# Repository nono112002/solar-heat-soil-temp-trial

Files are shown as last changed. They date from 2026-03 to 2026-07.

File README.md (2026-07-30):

# 太陽熱養生 温度測定プロジェクト

太陽熱を利用した土壌養生（消毒）の効果を「感覚」ではなく「データ」で検証する。
畑の複数地点・複数深度に温度センサーを設置し、リアルタイムで計測・記録・可視化するIoTシステム。

---

## システム概要図

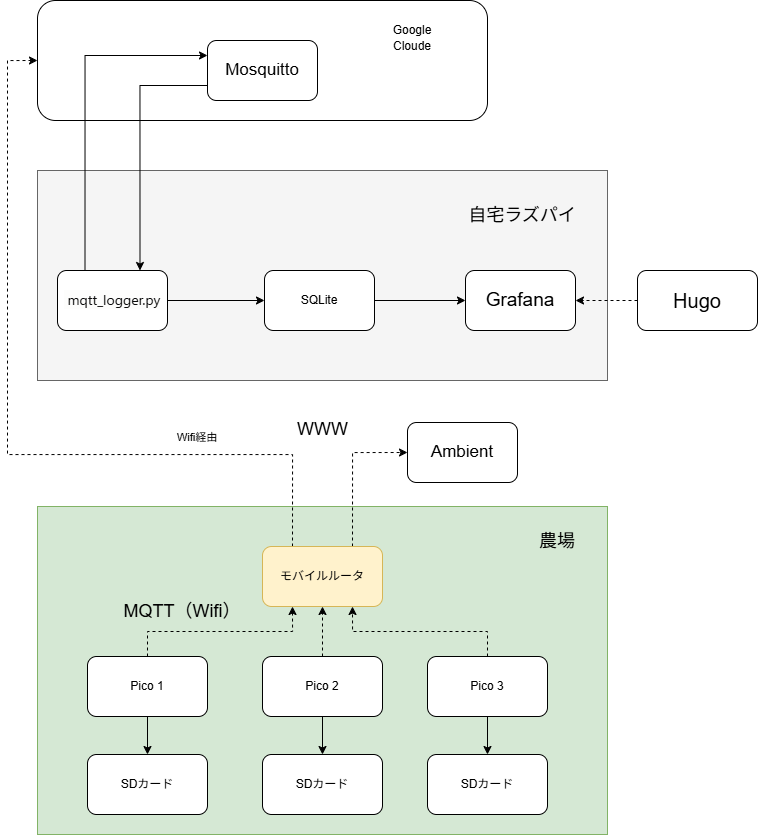
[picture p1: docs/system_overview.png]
システム概要図


### データの流れ

1. **農場の PicoBox（3台）** が30分ごとに温度を計測
2. **カシムラ モバイルルータ**（SORACOM SIM）経由で WiFi → LTE でインターネットに出る
3. **Google Cloud（GCE）上の Mosquitto** が MQTT メッセージを受信
4. **GCE の mqtt_logger** が SQLite に保存 + **Flask API** で配信
5. **自宅の Raspberry Pi** も GCE の MQTT を購読し、ローカル SQLite に保存
6. **Grafana**（ラズパイ）と **ポートフォリオHP**（GitHub Pages）でグラフ表示

> データは GCE（API配信用）と自宅ラズパイ（Grafana用）の2箇所に保存される。

---

## ブラウザからの確認方法

自宅 LAN 内のPCから以下にアクセス：

| 画面 | URL | 内容 |
|---|---|---|
| Grafana ダッシュボード | http://192.168.0.10:3000 | Zone-A/B/C の温度グラフ（メインの確認画面） |
| ポートフォリオ HP | http://192.168.0.10:1313 | プロジェクト紹介ページ |
| ライブデータ（3分割） | http://192.168.0.10:1313/dashboard.html | Grafana の3パネルを iFrame で一覧表示 |

> Grafana は匿名アクセス有効（ログイン不要）。ポートフォリオ HP（Hugo）は手動起動が必要（後述）。

---

## ハードウェア構成

### PicoBox（3台共通）

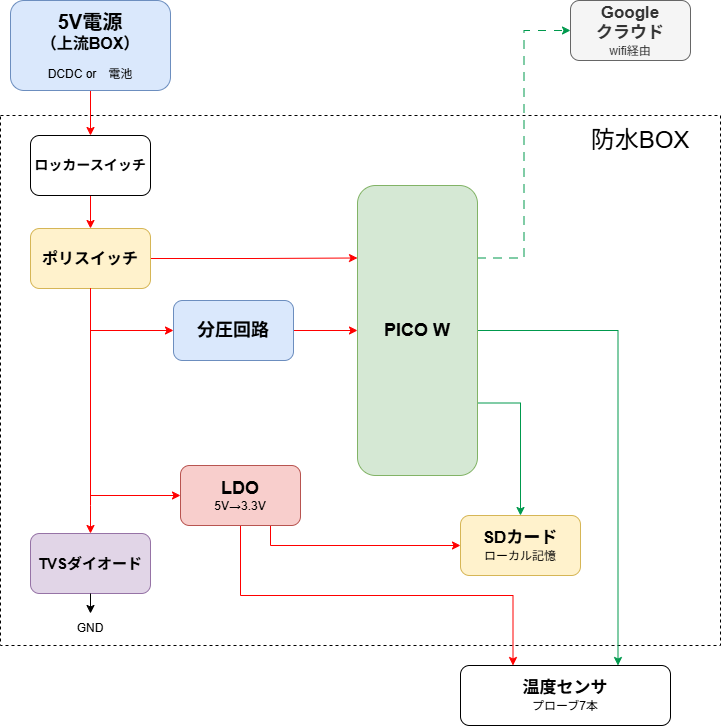
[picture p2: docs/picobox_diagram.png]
PicoBox 回路構成


| 部材 | 仕様 | 数量 |
|---|---|---|
| Raspberry Pi Pico W | RP2040 + CYW43439 | 3 |
| 温度センサー | DS18B20（防水型） | 21（7本 × 3台） |
| PCB（PicoBox） | JLCPCB 発注・自作基板 | 3 |
| SDカード | ローカルバックアップ用 | 3 |
| 防水BOX | 屋外設置用 | 3 |

### GPIO 割り当て（3台共通）

| 機能 | GPIO |
|---|---|
| DS18B20 × 7（S1〜S7） | GP8〜GP14 |
| SDカード（SPI） | GP2〜GP5、CD=GP6 |
| TX LED | GP15 |
| 主電源監視（ADC） | GP26 |

### センサー配置（1台あたり7本）

| ラベル | 位置 | 深さ |
|---|---|---|
| S1_center_10cm | 中央 | 10cm |
| S2_center_25cm | 中央 | 25cm |
| S3_center_40cm | 中央 | 40cm |
| S4_edge_10cm | エッジ | 10cm |
| S5_edge_25cm | エッジ | 25cm |
| S6_edge_40cm | エッジ | 40cm |
| S7_outdoor | 外気温 | — |

### ゾーン区分

| ゾーン | 区 | 処理内容 |
|---|---|---|
| zone-a | 区A | 標準区（たい肥＋菌＋ビニール） |
| zone-b | 区B | 対照・菌なし（たい肥＋ビニール） |
| zone-c | 区C | 対照・ビニールなし（たい肥のみ） |

### PicoBox ↔ ゾーン対応

| PicoBox筐体 | config.py ZONE | 設置エリア |
|---|---|---|
| ユニット3 | `zone-a` | 区A（標準区） |
| ユニット2 | `zone-b` | 区B（対照・菌なし） |
| ユニット1 | `zone-c` | 区C（対照・ビニールなし） |

> 筐体番号と区が一致しないが、config.py の ZONE で正しいゾーン名を送信するため
> DB上は常に物理エリアと一致する。

### 通信機器

| 機器 | 型番 | 役割 |
|---|---|---|
| モバイルルータ | カシムラ KD-249 | PicoBox の WiFi アクセスポイント → LTE 接続 |
| SIM | SORACOM Air plan-K2（KDDI） | モバイルデータ通信（月500MB、実使用量 約1.1MB/月） |

---

## サーバー構成（Raspberry Pi 4）

| コンポーネント | バージョン | 役割 | 自動起動 |
|---|---|---|---|
| mqtt_logger.py | Python 3.13 / paho-mqtt 2.1.0 | GCE の MQTT を購読 → SQLite に保存 | systemd ✅ |
| SQLite | 3.46.1 | データ保存（/var/lib/solar-heat/data.db） | — |
| Grafana | 13.0.1 + frser-sqlite-datasource | データ可視化（:3000） | systemd ✅ |
| Mosquitto | 2.0.21 | ローカル MQTT ブローカー（現在未使用） | systemd ✅ |
| Hugo | 0.131.0 + Blowfish v2.88.1 | ポートフォリオ HP（:1313） | **手動起動** |

### ラズパイの情報

| 項目 | 値 |
|---|---|
| OS | Debian 13 (trixie) aarch64 |
| ホスト名 | hp-server |
| IPアドレス | 192.168.0.10 |
| ストレージ | 28GB（24% 使用） |
| RAM | 3.7GB |

---

## クラウド構成（Google Cloud）

MQTT の中継サーバーとして GCE を使用。農場（モバイル回線）と自宅（固定回線）を繋ぐ。

| 項目 | 値 |
|---|---|
| プロジェクト | solar-heat-mqtt |
| VM名 | mqtt-broker |
| マシンタイプ | e2-micro（無料枠） |
| リージョン | us-central1-a |
| 外部IP | 34.58.138.105 |
| OS | Debian 12 (bookworm) |
| サービス | Mosquitto 2.0.11（:1883、認証あり）、mqtt_logger、Flask API（gunicorn :5000） |
| DB | /var/lib/solar-heat/data.db |
| API | https://34-58-138-105.sslip.io/api/（nginx + certbot SSL） |

---

## ソフトウェア構成

### ファイル一覧

```
solar-heat/
├── README.md                          # 本ファイル
├── pico/
│   ├── main.py                        # Pico W ファームウェア（MicroPython）
│   ├── config.py                      # WiFi/MQTT/ゾーン設定（.gitignore）
│   └── test_power_led.py              # LED テスト用
├── server/
│   ├── README.md                      # Pi セットアップ手順
│   ├── mqtt_logger.py                 # MQTT → SQLite 保存
│   ├── mqtt_logger.service            # systemd ユニットファイル
│   ├── mosquitto/
│   │   └── mosquitto.conf             # MQTT ブローカー設定
│   └── grafana/
│       └── provisioning/
│           ├── datasources/sqlite.yml
│           ├── dashboards/dashboards.yml
│           └── dashboards/solar-heat.json
├── docs/
│   ├── system_overview.png            # システム概要図
│   ├── picobox_diagram.png            # PicoBox 回路構成図
│   ├── server_design.md               # サーバー設計書（詳細）
│   ├── sensor_registry.md             # センサー台帳
│   ├── pcb_spec.md                    # PCB 設計仕様
│   ├── parts.md                       # 部品表
│   └── blog/                          # ブログ記事素材
└── kicad/                             # PCB 設計データ（KiCad）

GCE 上の配置（リポジトリ外、VM 内に直接配置）:
/home/nono/solar-heat/server/mqtt_logger.py  # MQTT ロガー（サービス実行元）
/var/lib/solar-heat/data.db                  # SQLite DB（API配信元）
/etc/systemd/system/mqtt_logger.service
```

### Pico ファームウェアの動作

`pico/main.py` は以下のサイクルを30分ごとに繰り返す：

1. DS18B20 × 7本から温度を読み取り
2. SDカードに CSV で記録（ローカルバックアップ）
3. WiFi ON → カシムラに接続
4. MQTT で GCE に温度データを送信（`solar-heat/{zone}/{label}`）
5. MQTT でデバイスステータスを送信（`solar-heat/{zone}/status`）
6. 電源電圧が 4.0V 未満なら電源アラートを送信
7. WiFi OFF → スリープ（ウォッチドッグタイマー feed しながら）

**ウォッチドッグタイマー**: 8秒タイムアウト。熱暴走等でフリーズした場合に自動リセットする。
起動直後に有効化され、メインループ内の各ステップおよびスリープ中（1秒ごと）に feed する。

### LED 表示パターン

| 状態 | 意味 |
|---|---|
| 消灯 | 正常 |
| 常時点灯 | 電源異常（bus_v < 4.0V） |
| 低速点滅 | SD異常 |
| 高速点滅 | 電源異常 + SD異常 |

### MQTT トピック

| トピック | ペイロード例 |
|---|---|
| `solar-heat/zone-a/S1_center_10cm` | `{"time": "2026-07-12T16:00:00", "temp": 29.88}` |
| `solar-heat/zone-a/status` | `{"zone": "zone-a", "bus_v": 5.02, "sd_status": "ok", "uptime_min": 120}` |
| `solar-heat/zone-a/power_alert` | `{"zone": "zone-a", "bus_v": 3.8, "alert": "main_power_lost"}` |

### SQLite テーブル

| テーブル | カラム | 内容 |
|---|---|---|
| temperature | timestamp, zone, label, temp | 温度データ |
| device_status | zone, bus_v, sd_status, wifi_attempts, uptime_min | デバイス状態 |
| power_alert | zone, bus_v, alert | 電源異常アラート |

---

## セットアップ手順

### 1. Raspberry Pi

詳細は `server/README.md` を参照。

```bash
# リポジトリ取得
cd ~ && git clone https://github.com/nono112002/solar-heat-soil-temp-trial.git solar-heat

# Mosquitto（ローカル、現在未使用だが残してある）
sudo ln -s ~/solar-heat/server/mosquitto/mosquitto.conf /etc/mosquitto/conf.d/solar-heat.conf
sudo systemctl restart mosquitto

# SQLite 保存先
sudo mkdir -p /var/lib/solar-heat && sudo chown nono:nono /var/lib/solar-heat

# mqtt_logger サービス
sudo ln -s ~/solar-heat/server/mqtt_logger.service /etc/systemd/system/mqtt_logger.service
sudo systemctl daemon-reload && sudo systemctl enable --now mqtt_logger

# Grafana（別途 apt で導入済み）
# プラグイン: grafana cli plugins install frser-sqlite-datasource
```

### 2. PicoBox（各台）

```bash
# ファームウェア書き込み（USB 接続状態で）
mpremote connect COMx fs cp pico/main.py :main.py
mpremote connect COMx fs cp pico/config.py :config.py
```

`config.py` は `.gitignore` で管理外。各台で ZONE と SENSOR_PINS を設定する。
リポジトリに `config_pico1.py` / `config_pico2.py` / `config_pico3.py` を用意してある。

```python
# config_example.py を参照。実際の値は config_pico*.py に記入（gitignore対象）
WIFI_SSID     = "your_ssid"
WIFI_PASSWORD = "your_password"
MQTT_BROKER   = "your_mqtt_host"
MQTT_PORT     = 1883
MQTT_USER     = "your_user"
MQTT_PASS     = "your_pass"
ZONE          = "zone-a"  # zone-a / zone-b / zone-c
```

### 3. Hugo（ポートフォリオ HP）

```bash
# ラズパイで実行
cd ~ && git clone https://github.com/nono112002/nono112002.github.io.git portfolio
cd portfolio && git submodule update --init --recursive

# 起動（手動）
hugo server --bind 0.0.0.0 --baseURL http://192.168.0.10 -p 1313
```

### 4. Google Cloud（MQTT 中継 + バックアップ）

```bash
# gcloud CLI でセットアップ済み
# プロジェクト: solar-heat-mqtt
# VM: mqtt-broker (e2-micro, us-central1-a)
# Mosquitto 認証: server/.env を参照
# ファイアウォール: tcp:1883 を開放

# バックアップロガー
# /opt/solar-heat/mqtt_logger.py — ローカル Mosquitto を購読し SQLite に保存
# /var/lib/solar-heat/data.db — ラズパイと同一スキーマのバックアップDB
# systemd: mqtt_logger.service（自動起動）
```

---

## 運用コマンド集

### ラズパイ（SSH: `ssh nono@192.168.0.10`）

```bash
# ログ確認
journalctl -u mqtt_logger -f

# MQTT 受信状況をリアルタイム確認
mosquitto_sub -h $MQTT_HOST -u $MQTT_USER -P $MQTT_PASS -t 'solar-heat/#' -v

# DB 確認
sqlite3 /var/lib/solar-heat/data.db 'SELECT * FROM temperature ORDER BY id DESC LIMIT 10;'
sqlite3 /var/lib/solar-heat/data.db 'SELECT zone, COUNT(*) FROM temperature GROUP BY zone;'

# ソフト更新
cd ~/solar-heat && git pull && sudo systemctl restart mqtt_logger

# Hugo 起動
cd ~/portfolio && git pull --recurse-submodules
hugo server --bind 0.0.0.0 --baseURL http://192.168.0.10 -p 1313
```

### GCE（`gcloud compute ssh mqtt-broker --zone=us-central1-a`）

```bash
# Mosquitto ログ確認
sudo journalctl -u mosquitto -f

# 接続テスト
mosquitto_pub -h localhost -u $MQTT_USER -P $MQTT_PASS -t test/hello -m "test"

# バックアップロガー確認
sudo journalctl -u mqtt_logger -f
sqlite3 /var/lib/solar-heat/data.db 'SELECT * FROM temperature ORDER BY id DESC LIMIT 10;'
```

---

## ブログ記事

| 回 | タイトル | URL |
|---|---|---|
| 第1回 | 太陽熱養生とは / 実験設計 | https://note.com/nono399/ |
| 第2回 | 回路設計・PCB発注 | https://note.com/nono399/ |
| 第3回 | ファームウェアと自宅サーバー | https://note.com/nono399/n/nedf561051aac |

---

## 詳細ドキュメント

| ドキュメント | 内容 |
|---|---|
| [サーバー設計書](docs/server_design.md) | ラズパイの詳細構成・配置・ハマりポイント |
| [センサー台帳](docs/sensor_registry.md) | 各 Pico のセンサー割り当て・DS18B20 ID |
| [PCB 設計仕様](docs/pcb_spec.md) | PicoBox 基板の設計仕様 |
| [部品表](docs/parts.md) | 購入部品一覧 |

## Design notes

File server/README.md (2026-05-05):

# Solar-Heat サーバー（Raspberry Pi）

PicoBox から MQTT で送られる温度データを受信して SQLite に保存する。

詳細設計は [`docs/server_design.md`](../docs/server_design.md) を参照。

## 構成

| サービス | 役割 |
|---|---|
| Mosquitto (apt) | MQTT ブローカー |
| `mqtt_logger.py` (Python) | MQTT 購読 → SQLite 書き込み（systemd 常駐） |
| Grafana (apt) | 可視化（後で追加） |

## Pi セットアップ手順

### 1. 基本パッケージ

```bash
sudo apt update && sudo apt upgrade -y
sudo apt install -y git mosquitto mosquitto-clients python3-paho-mqtt
```

### 2. リポジトリ取得

```bash
cd ~
git clone https://github.com/nono112002/solar-heat-soil-temp-trial.git solar-heat
cd solar-heat
```

### 3. Mosquitto 設定（シンボリックリンク）

```bash
sudo ln -s ~/solar-heat/server/mosquitto/mosquitto.conf /etc/mosquitto/conf.d/solar-heat.conf
sudo systemctl restart mosquitto
sudo systemctl enable mosquitto
```

### 4. SQLite 保存先ディレクトリ作成

```bash
sudo mkdir -p /var/lib/solar-heat
sudo chown pi:pi /var/lib/solar-heat
```

### 5. mqtt_logger サービス起動

```bash
sudo ln -s ~/solar-heat/server/mqtt_logger.service /etc/systemd/system/mqtt_logger.service
sudo systemctl daemon-reload
sudo systemctl enable mqtt_logger
sudo systemctl start mqtt_logger
```

### 6. 動作確認

別ターミナルでMQTTを直接購読して、Picoが送信しているか確認：

```bash
mosquitto_sub -h localhost -t 'solar-heat/#' -v
```

ログ確認：

```bash
journalctl -u mqtt_logger -f
```

SQLite 中身確認：

```bash
sqlite3 /var/lib/solar-heat/data.db 'SELECT * FROM temperature ORDER BY id DESC LIMIT 10;'
```

## アップデート

開発機でコミット・プッシュ後、Pi 側で：

```bash
cd ~/solar-heat
git pull
sudo systemctl restart mqtt_logger
```

設定ファイルやスクリプトはシンボリックリンクなので、`git pull` で自動反映される。

## トラブルシューティング

| 症状 | 確認 |
|---|---|
| `mqtt_logger` が起動しない | `journalctl -u mqtt_logger -n 50` |
| MQTTメッセージが来ない | `mosquitto_sub -h localhost -t '#' -v` で全トピック監視 |
| Pico 側が接続できない | Pico の `config.py` の `MQTT_BROKER` が Pi の IP/ホスト名になっているか |
| ファイアウォール | `sudo ufw status`（Bookworm標準では無効のはず） |

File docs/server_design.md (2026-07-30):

# サーバー設計書

最終更新: 2026-07-20

## 目的

PicoBox（区A/B/C 各台）から送られてくる温度データを収集・蓄積・可視化する。
農場に設置したモバイルルーター経由でクラウド（GCE）にMQTT送信し、自宅のRaspberry Piで可視化する。

**設計方針**: 手間を最小化する。Dockerやコンテナ抽象化は使わず、apt install と Python で完結させる。

## 全体構成

```
┌─────────────┐  ┌─────────────┐  ┌─────────────┐
│ PicoBox A   │  │ PicoBox B   │  │ PicoBox C   │
│ (区A 標準)  │  │ (区B 対照)  │  │ (区C ビニールなし)│
└──────┬──────┘  └──────┬──────┘  └──────┬──────┘
       │ MQTT (WiFi)    │                │
       └────────────────┴────────────────┘
                        │
                        ▼
        ┌──────────────────────────────┐
        │ カシムラ KD-249 モバイルルーター │  ← 農場設置
        │ (SORACOM plan-K2 SIM)        │
        └──────────────┬──���────────────┘
                       │ LTE
                       ▼
┌──────────────────────────────────────────────────┐
│  GCE (mqtt-broker / 34.58.138.105)               │
│  e2-micro (1GB RAM), us-central1-a               │
│                                                   │
│  ┌──────────────┐    ┌──────────────────┐        │
│  │ Mosquitto    │───>│ mqtt_logger.py   │        │
│  │ :1883       │    │ (バックアップ用)  │        │
│  │ (��証あり)   ��    └────────┬─────────┘        │
│  └──────────────┘             │                   │
│                               ▼                   │
│                    /var/lib/solar-heat/data.db     │
│                    (SQLite バックアップ)           │
└──────────────────────────────────────────────────┘
                       │
              MQTT subscribe (LAN→WAN)
                       │
┌──────────────────────────────────────────────────┐
│  Raspberry Pi 4（hp-server / 192.168.0.10）      │
│  Debian 13 (trixie) aarch64                      │
│  SD: 28GB / RAM: 3.7GB                           │
│                                                   │
│  ┌───────────���──────┐                            │
│  │ mqtt_logger.py   │  �� GCE Mosquittoを購読    │
│  │ (systemdサービス)│                            │
│  └────────┬─────────┘                            │
│           │                                       │
│           ▼                                       │
│  ┌────────────────────────┐                      │
│  │ /var/lib/solar-heat/   │                      │
│  │   data.db (SQLite)     │  ← 本番データ       │
│  └─────────��┬─────────────┘                      │
│             │                                     │
│             ▼                                     │
│  ┌────────────────────────┐                      │
│  │ Grafana :3000          │                      │
│  │ + frser-sqlite-datasource v4.0.2             │
│  └────────────────────────┘                      │
└──────────────────────────────────────────────────┘
```

## コンポーネント一覧

### GCE (mqtt-broker)

| 役割 | 採用 | バージョン | 備考 |
|---|---|---|---|
| MQTTブローカー | Mosquitto | 2.0.x | パスワード認証���server/.env を参照） |
| MQTT購読・保存 | mqtt_logger.py | Python 3.x | /home/nono/solar-heat/server/ から実行 |
| データ保存 | SQLite | 3.x | /var/lib/solar-heat/data.db |
| データAPI | Flask + gunicorn | Python 3.x | :5000、nginx経由で HTTPS 公開 |
| リバースプロキシ | nginx + certbot | — | 34-58-138-105.sslip.io（Let's Encrypt SSL） |

### Raspberry Pi (hp-server)

| 役割 | 採用 | バージョン | 備考 |
|---|---|---|---|
| MQTT購読・保存 | Python + paho-mqtt | Python 3.13.5 / paho-mqtt 2.1.0 | GCE Mosquittoを購読 |
| データ保存 | SQLite | 3.46.1 | /var/lib/solar-heat/data.db（本番） |
| 可視化 | Grafana + frser-sqlite-datasource | 13.0.1 / v4.0.2 | LAN内アクセスのみ |

## ネットワーク・ポート

| サービス | ホスト | ポート | 公開範囲 |
|---|---|---|---|
| Mosquitto | GCE (34.58.138.105) | 1883 | インターネット（認証必須） |
| Grafana | Pi (192.168.0.10) | 3000 | LAN内 |

### GCE ファイアウォールルール

| ルール名 | ポート | 用途 |
|---|---|---|
| allow-mqtt | tcp:1883 | PicoBox → Mosquitto |
| default-allow-ssh | tcp:22 | 管理用 |

## データフロ���

### Picoが送るMQTTメッセージ

30分間隔（INTERVAL_SEC = 1800）で発行：

| トピック | ペイロード（JSON） |
|---|---|
| `solar-heat/{zone}/{label}` | `{"time": "2021-01-01T...", "temp": 25.5}` |
| `solar-heat/{zone}/status` | `{"zone": "...", "bus_v": 5.06, "sd_status": "mount_failed", ...}` |
| `solar-heat/{zone}/power_alert` | `{"zone": "...", "bus_v": 4.0, "alert": "main_power_lost"}` |

> **注意**: `time` フィールドはPicoのRTC（NTP同期失敗で2021-01-01固定）。
> 正確な時刻は `received_at`（サーバー側付与UTC）を使用する。

### ゾーン・ラベル対応

各 PicoBox の `config.py` で正しい ZONE と SENSOR_PINS を設定しているため、
Pico が送信するデータはそのまま正しいゾーン名・ラベルで DB に保存される。
サーバー側での変換処理（ZONE_REMAP / LABEL_REMAP）は 2026-07-20 に廃止。

| PicoBox筐体 | config.py ZONE | 物理エリア |
|---|---|---|
| ユニット3 | zone-a | 区A（標準区） |
| ユニット2 | zone-b | 区B（対照・菌なし） |
| ユニット1 | zone-c | 区C（対照・ビニールなし） |

センサープローブの入替は `config.py` の `SENSOR_PINS` で対応（詳細は `docs/sensor_registry.md`）。

### SQLiteスキーマ

```sql
CREATE TABLE temperature (
    id          INTEGER PRIMARY KEY AUTOINCREMENT,
    timestamp   TEXT NOT NULL,    -- Picoが送るISO8601（2021-01-01固定、参考値）
    received_at TEXT NOT NULL,    -- サーバー側の受信時刻（UTC、正確）
    zone        TEXT NOT NULL,
    label       TEXT NOT NULL,
    temp        REAL NOT NULL
);
CREATE INDEX idx_temp_zone_ts ON temperature(zone, timestamp);

CREATE TABLE device_status (
    id          INTEGER PRIMARY KEY AUTOINCREMENT,
    received_at TEXT NOT NULL,
    zone        TEXT NOT NULL,
    bus_v       REAL,
    sd_status   TEXT,
    wifi_attempts INTEGER,
    uptime_min  INTEGER
);

CREATE TABLE power_alert (
    id          INTEGER PRIMARY KEY AUTOINCREMENT,
    received_at TEXT NOT NULL,
    zone        TEXT NOT NULL,
    bus_v       REAL,
    alert       TEXT
);
```

## Grafana ダッシュボード

UID: `solar-heat-main`
URL: `http://192.168.0.10:3000/d/solar-heat-main/solar-heat-temperature-monitor`

| Panel ID | タイトル | 内容 |
|---|---|---|
| 1 | All Zones - Center 10cm | 全ゾーンのS1比較（3線） |
| 10 | Zone A (Standard) | zone-a 全7センサー（7線） |
| 20 | Zone B (Control-noMicrobe) | zone-b 全7センサー（7線） |
| 30 | Zone C (Control-noVinyl) | zone-c 全7センサー（7線） |
| 40 | Depth - Center | 中央深度比較 A/B/C × 10/25/40cm（9線） |
| 41 | Depth - Edge | 辺縁深度比較 A/B/C × 10/25/40cm（9線） |
| 50 | Device Status | 最新デバイス状態テーブル |

### クエリ設計上の注意

- **frser-sqlite-datasource の `queryType: "time series"` はバグで使用不可**（v4.0.2, v4.0.6共に "can not convert to wide series" エラー）
- `queryType: "table"` を使用し、SQLでワイドフォーマット（PIVOT）に変換
- 時刻���ラムは `CAST(CAST(unixepoch(received_at)/60 AS INT)*60 AS REAL)*1000` （分丸めエポックms）
- `convertFieldType` トランスフォーメーションで `time` を時間型に変換
- `$__from / 1000` と `$__to / 1000` でGrafanaの時間範囲フィルタ��用
- Go バックエンドは `queryText` フィールドを読む（`rawQueryText` はフロントエンド用、両方記載）

## アクセス情報

| 項目 | 値 |
|---|---|
| **GCE** | |
| インスタンス名 | mqtt-broker |
| IP | 34.58.138.105 |
| SSH | `gcloud compute ssh nono@mqtt-broker --zone=us-central1-a` |
| MQTT認証 | server/.env を参照 |
| **Raspberry Pi** | |
| ホスト名 | hp-server |
| IP | 192.168.0.10 |
| SSH | `ssh nono@192.168.0.10` |
| Grafana URL | http://192.168.0.10:3000 |
| Grafana ダッシュボードUID | `solar-heat-main` |
| Datasource UID | `P648C6F40D76405CF` |
| SQLite DB | `/var/lib/solar-heat/data.db` |

## よく使うコマンド

```bash
# === GCE ===
# MQTT受信確認
gcloud compute ssh nono@mqtt-broker --zone=us-central1-a --command="mosquitto_sub -h localhost -u $MQTT_USER -P $MQTT_PASS -t 'solar-heat/#' -v"

# GCE mqtt_logger ログ
gcloud compute ssh nono@mqtt-broker --zone=us-central1-a --command="journalctl -u mqtt_logger -f"

# GCE バックアップDB確認
gcloud compute ssh nono@mqtt-broker --zone=us-central1-a --command="sqlite3 /var/lib/solar-heat/data.db 'SELECT zone, count(*), max(received_at) FROM temperature GROUP BY zone'"

# === Raspberry Pi ===
# mqtt_logger ログ
ssh nono@192.168.0.10 "journalctl -u mqtt_logger -f"

# DB確認
ssh nono@192.168.0.10 "sqlite3 /var/lib/solar-heat/data.db 'SELECT zone, count(*), max(received_at) FROM temperature GROUP BY zone'"

# ソフト更新
ssh nono@192.168.0.10 "cd ~/solar-heat && git pull && sudo systemctl restart mqtt_logger"

# Grafana ダッシュボード更新
ssh nono@192.168.0.10 "sudo cp ~/solar-heat/server/grafana/provisioning/dashboards/solar-heat.json /etc/grafana/provisioning/dashboards/ && sudo systemctl restart grafana-server"
```

## systemd サービス一覧

### GCE

| サービス | 状態 | 備考 |
|---|---|---|
| `mosquitto.service` | active/enabled | MQTTブローカー（認証あり） |
| `mqtt_logger.service` | active/enabled | バックアップ用データ収集 |

### Raspberry Pi

| サービス | 状態 | 備考 |
|---|---|---|
| `mqtt_logger.service` | active/enabled | GCE MQTTを購読 → SQLite保存 |
| `grafana-server.service` | active/enabled | 可視化（LAN内） |

## 既知の制約・課題

- **Pico RTC不正確**: NTP同期に失敗するため `timestamp` は常に 2021-01-01。`received_at` を正とする
- **SDカードマウント失敗**: 全PicoBoxで赤LED点滅（MCP1703ハンダ不良 or SDカード接触���良の可能性）
- **外部からのGrafana閲覧不可**: Pi は LAN内のみ。GitHub Pages (HTTPS) からの HTTP iframe は mixed content でブロックされる
- **GCE mosquitto.conf**: リポジトリ上の `server/mosquitto/mosquitto.conf` にはWebSocket (9001) の設定があるが、GCE���番では未適用（1883のみ）

## 更新履歴

- **2026-07-20**: ZONE_REMAP / LABEL_REMAP をサーバーから廃止。各Picoのconfig.pyで正しいZONE・SENSOR_PINSを設定する方式に変更。ウォッチドッグタイマー追加。Flask API + nginx SSL追加。
- **2026-07-19**: 圃場設置、ZONE_REMAP / LABEL_REMAP 導入。
- **2026-07-12**: GCE MQTTブローカー移設。

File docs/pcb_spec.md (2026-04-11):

# PCB 設計仕様書 - PicoBox 基板

## システム構成概要

```
【上流電源ボックス】（1台）
  24V入力 → DC-DC 5V変換 ─[D1: 逆接防止]──┐
  電池ボックス(単3×3本=4.5V) ─[D2: Schottky]─┴──→ 5V バス出力
                                                   ├──→ PicoBox A（区A）
                                                   ├──→ PicoBox B（区B）
                                                   └──→ PicoBox C（区C）

【PicoBox】（3台、同一設計）
  5V バス入力 → ポリスイッチ → Pico W + SDカード + センサー端子台
```

---

## 上流電源ボックス 回路

### ダイオードOR回路（バックアップ切り替え）

```
24V → DC-DC 5V converter ─[D1: 1N5819（逆接防止のみ）]──┐
                                                          ├──→ 5V バス → 各PicoBoxへ
電池ボックス(単3×3本=4.5V) ──────[D2: Schottky 1N5819]──┘
```

**動作原理**:
- 主電源ON: バス = 5V、電池4.5V < 5V のためD2が逆バイアス（電池から電流流れない）
- 主電源OFF: 電池→D2→4.2V がバスに供給、3台のPicoへ無停止で切り替わる

**電池バックアップ持続時間（参考）**:
| 状態 | 3台合計電流 | 単3×3本（2500mAh）持続時間 |
|---|---|---|
| 平均（30分に1回送信） | ~30mA | ~80時間（約3日） |
| 待機のみ | ~15mA | ~170時間（約7日） |

### 上流ボックス 部品リスト

| 部品 | 仕様 | 数量 | 購入先・品番 | 備考 |
|---|---|---|---|---|
| DC-DCコンバーター | MEAN WELL SD-15B-05（18-36VDC→5V/3A） | 1 | Mouser 709-SD15B-05 | シャーシマウント、24V入力対応 |
| ショットキーダイオード | 1N5819 | 2 | 秋月 | D1（逆接防止）、D2（電池OR） |
| 電池ボックス | 単3×3本（4.5V） | 1 | 秋月 | フェルール端子で接続 |
| 出力端子台 | 2ピン × 3 | 3 | 秋月 | 各PicoBoxへの5V出力 |
| TVSダイオード | P6KE6.8CA-TB（双方向） | 1 | Mouser 576-P6KE6.8CA-TB | 24V入力サージ保護 |

---

## PicoBox 回路

### 外部接続（フェルール端子 + WAGO/Phoenix）

| 端子 | 信号 | 備考 |
|---|---|---|
| 5V IN / GND | 電源入力（上流ボックスから） | 2ピン端子台 |
| DS18B20 × 7本 | VCC / DATA / GND | 3ピン端子台 × 7 |

### GPIO ピン割り当て

| GPIO | 機能 | 接続先 |
|---|---|---|
| GP2  | SPI0 SCK  | SDカード |
| GP3  | SPI0 MOSI | SDカード |
| GP4  | SPI0 MISO | SDカード |
| GP5  | SPI0 CS | SDカード |
| GP6  | SD カード検出（挿入時 LOW） | SDモジュール CD ピン + PULL_UP |
| GP7  | 1-Wire BUS（全センサー共通） | DS18B20 最大7本 + 4.7kΩ → 3V3 |
| GP15 | TX LED（送信時点滅） | LED + 330Ω → GND |
| GP_MON（未定） | 主電源監視 | 分圧回路（10kΩ/10kΩ）→ GPIO |
| VSYS | 電源入力 | 5V バスから |
| GND  | グラウンド | 共通 |

> **変更履歴**: GP16-19 → GP2-5（2026-03-29）/ GP20 → GP6（SD card detect）

### 電源入力部

```
5V バス入力
  → ポリスイッチ 500mA（自動復帰ヒューズ）
  → スライドスイッチ（ON/OFF）
  → VSYS（Pico W）
  → MCP1703-3302（外部LDO）→ 3.3V（SD・センサー・LED用）
```

### 3.3V レギュレーター（外部LDO）

**MCP1703-3302（SOT-23）**
- ドロップアウト電圧: 250mV（電池バックアップ時 4.2V入力でも3.3V出力OK）
- AMS1117-3.3は不可（ドロップアウト1.5V、4.2V入力では不足）

```
5V バス → MCP1703-3302 → 3.3V
            入力: 100nF セラコン
            出力: 10µF セラコン
```

PicoのWiFi（内部3.3V）とSD・センサーの3.3Vが完全分離 → 電圧干渉なし。

### 主電源監視回路（電源断アラート）

```
5V バス ─[R1: 10kΩ]─┬─[R2: 10kΩ]─ GND
                     └──→ GP_MON（約2.5V → Pico が HIGH 認識）
```

- 主電源あり → HIGH → 通常動作
- 主電源なし → LOW → ファームウェアがMQTTアラート送信（電池残量中に送出）

### DS18B20 接続部（個別GPIO方式）

各センサーを専用GPIOに1対1接続。IDスキャン・sensor_map不要。
1本が故障してもバス全滅しない。交換もピンに挿し直すだけ。

```
+3V3_EXT → 4.7kΩ → GP8  → DS18B20 S1（中央 10cm）
+3V3_EXT → 4.7kΩ → GP9  → DS18B20 S2（中央 25cm）
+3V3_EXT → 4.7kΩ → GP10 → DS18B20 S3（中央 40cm）
+3V3_EXT → 4.7kΩ → GP11 → DS18B20 S4（エッジ 10cm）
+3V3_EXT → 4.7kΩ → GP12 → DS18B20 S5（エッジ 25cm）
+3V3_EXT → 4.7kΩ → GP13 → DS18B20 S6（エッジ 40cm）
+3V3_EXT → 4.7kΩ → GP14 → DS18B20 S7（外気温）
```

各ラインに 100Ω 直列抵抗（GPIO保護）を追加。
プルアップ 4.7kΩ × 7本、直列 100Ω × 7本。

### SDカードモジュール（AE-MICRO-SD-DIP / 秋月電子）

**モジュール品番**: AE-MICRO-SD-DIP（秋月電子）
**接続モード**: SPI（4線式）
**KiCADコネクタ**: J9 = Conn_01x10（10ピン）

#### モジュールピン配置とSPIマッピング

| モジュールPin | 信号名 | SPIでの役割 | 接続先 | ネット名 |
|---|---|---|---|---|
| ① | DAT2 | 未使用（SPI不要） | NC | - |
| ② | CD/DAT3 | CS（チップセレクト） | GP5 | SD_CS |
| ③ | CMD | MOSI | GP3 | SD_MOSI |
| ④ | VDD | 電源 | +3V3_EXT | +3V3_EXT |
| ⑤ | CLK | SCK | GP2 | SD_SCK |
| ⑥ | VSS | GND | GND | GND |
| ⑦ | DAT0 | MISO | GP4 | SD_MISO |
| ⑧ | DAT1 | 未使用（SPI不要） | NC | - |
| ⑨ | カード検出スイッチB | CD（GPIO入力側） | GP6 | SD_CD |
| ⑩ | カード検出スイッチA | CD（GND側） | GND | GND |

> **カード検出スイッチ**: カード挿入時にスイッチが閉じ、⑨-⑩間が短絡。GP6をPULL_UP設定にすると、カード挿入時にLOW、未挿入時にHIGHとなる。
> **DAT1・DAT2**: SPIモードでは使用しない。NC（未接続）で問題なし（SD内部にウィークプルアップあり）。

#### Pico W GPIO割り当て（物理ピン4〜10）

| 物理ピン | GPIO | 機能 |
|---|---|---|
| 4 | GP2 | SCK  |
| 5 | GP3 | MOSI |
| 6 | GP4 | MISO |
| 7 | GP5 | CS |
| 8 | GND | GND  |
| 9 | GP6 | CD（カード検出） |
| 10 | GP7 | 1-Wire（DS18B20全センサー共通） |

**7ピン連続（物理ピン4〜10）で全信号線が片側に集約。**

### DS18B20 ライン保護

```
GP8〜GP14 各ピン → 100Ω直列抵抗 → センサーコネクタ DATA
理由: 静電気・誤配線時の GPIO ピン保護（7本分）
```

---

## 電源設計 注意事項（実機確認より）

**症状**: SD カードマウント失敗 / "timeout waiting for v2 card"

**原因**:
- Pico W の CYW43 WiFi チップが内部3V3レールを共有
- WiFi 動作中は 3V3 が 2.9V 以下に降下（**実測 2026-03-29**）
- Freenove 拡張ボードの 3V3 端子台の**ねじが緩んでいた**ことも一因

**PCBでの根本対策**:
- SD・センサーの3.3VはMCP1703-3302から供給 → WiFi干渉と完全分離
- ファームウェアの`wifi_off()`→SDマウントシーケンスは引き続き維持
- 教訓: **ねじ端子台は必ず締め付けトルクを確認すること**

---

## PicoBox 部品リスト（1台分）

最終更新: 2026-04-12（全部品の購入先・品番確定）

| 部品 | 仕様 | 数量 | 購入先・品番 | 備考 |
|---|---|---|---|---|
| Raspberry Pi Pico W | SC0918 | 1 | Mouser 358-SC0918 | ソケット経由で着脱可能 |
| Pico W ソケット | 1×20 メスピンソケット（片側1本 × 両側2本） | 2 | 秋月（在庫品） | Pico W両端に各1本ずつ実装 |
| DS18B20 コネクタ | JST PH 3ピン（基板側：B3B-PH-K） | 7 | 秋月（在庫品） | VCC/DATA/GND、GP8〜GP14 |
| SDカードモジュール ソケット | 1×10 メスピンソケット | 1 | 秋月（在庫品） | AE-MICRO-SD-DIP 対応 |
| 電源入力端子台 | Phoenix Contact SPTAF 1/2-3,5-EL（2ピン、3.5mmピッチ、フェルール直差し） | 1 | Mouser 651-1862042 | 5V IN（上流ボックスから） |
| LDO レギュレーター | MCP1703-3302E/DB（SOT-223） | 1 | Mouser 579-MCP1703-3302E/DB | 5V→3.3V、ドロップアウト250mV |
| TVSダイオード | P6KE6.8CA-TB（双方向、600W peak） | 1 | Mouser 576-P6KE6.8CA-TB（Littelfuse） | 電源入力サージ保護、向き不問 |
| リセッタブルヒューズ | MF-R050（500mA保持、1Aトリップ） | 1 | 秋月 112628 | 自動復帰ヒューズ |
| スライドスイッチ | SS-12SDP2（2.54mmピッチ） | 1 | 秋月 115643 | 電源ON/OFF |
| プルアップ抵抗 | 4.7kΩ 1/4W（炭素皮膜、100本袋） | 7 | 秋月 125472 | DS18B20 GP8〜GP14 各ライン |
| 分圧抵抗 | 10kΩ 1/4W（炭素皮膜、100本袋） | 2 | 秋月 125103 | 主電源監視 GP26（ADC0） |
| LED電流制限抵抗 | 330Ω 1/4W（炭素皮膜、100本袋） | 2 | 秋月 125331 | D2電源LED・D3 TX LED |
| LED 黄緑 | 3mm砲弾型 570nm（OSG8HA3Z74A） | 1 | 秋月 111637 | 電源表示（D2） |
| LED 赤 | 3mm砲弾型 625nm（OSR5JA3Z74A） | 1 | 秋月 111577 | TX表示（D3） |
| 電解コンデンサ | 100µF / 35V φ6.3mm P2.5mm（C4） | 1 | 秋月 102724（Rubycon ZLH） | +5V_SW バルクデカップリング |
| 電解コンデンサ | 10µF / 50V φ5mm P2.0mm（C3） | 1 | 秋月 117897（Rubycon PX） | LDO出力安定化（+3V3_EXT） |
| セラミックコンデンサ | 100nF / 630V X7R P5.0mm（C1） | 1 | 秋月 110149（muRata） | LDO入力バイパス |
| セラミックコンデンサ | 100nF / 630V X7R P5.0mm（C2） | 1 | 秋月 110149（muRata） | LDO出力バイパス |

---

## 基板サイズ・外形

- PicoBox: 目安 80×60mm（防水ボックス 220×170×110mm に収まるサイズ）
- Pico W はソケット実装（着脱可能）
- 基板3枚同一設計（区A/B/C 共通）

---

## 発注先候補

| 業者 | 最小ロット | 備考 |
|---|---|---|
| JLCPCB | 5枚〜 | 最安、2層基板$2〜 |
| PCBWay | 5枚〜 | 品質高め |

→ 3枚必要なので5枚発注が最小ロット

---

## KiCAD 作業チェックリスト

### 上流電源ボックス
- [ ] 回路図作成
- [ ] PCB レイアウト（またはケース内配線図）

### PicoBox（共通設計）
- [x] 回路図（Schematic）作成
- [x] PCB レイアウト
- [x] デザインルールチェック（DRC）　エラー0件確認済み
- [x] Gerber ファイル出力
- [x] JLCPCB発注（5枚、$4.64、OCS Express）2026-04-12
- [ ] 部品実装（PCB到着後）
- [ ] 動作確認

## 調達状況（2026-04-12）

### Mouser 発注済み
| 品番 | 部品 | 数量 |
|---|---|---|
| 358-SC0918 | Raspberry Pi Pico W | 3 |
| 579-MCP1703-3302E/DB | LDO 3.3V | 5 |
| 651-1862042 | 端子台 SPTAF 2P | 5 |
| 576-P6KE6.8CA-TB | TVS ダイオード | 5 |
| 709-SD15B-05 | DC-DC 5V/3A（上流ボックス用） | 1 |

### 秋月電子 発注済み
| 品番 | 部品 | 数量 |
|---|---|---|
| 112628 | MF-R050 ポリスイッチ | 5 |
| 115643 | SS-12SDP2 スライドSW | 5 |
| 117897 | 電解コン 10µF/50V | 5 |
| 102724 | 電解コン 100µF/35V | 5 |
| 110149 | セラコン 0.1µF | 10 |
| 111577 | LED 赤 3mm | 5 |
| 111637 | LED 黄緑 3mm | 5 |
| 125472 | 抵抗 4.7kΩ 100本袋 | 1 |
| 125103 | 抵抗 10kΩ 100本袋 | 1 |
| 125331 | 抵抗 330Ω 100本袋 | 1 |

### 在庫品（発注不要）
- 1×20 メスピンソケット
- B3B-PH-K（JST PH 3P）
- 1×10 メスピンソケット（SDモジュール用）

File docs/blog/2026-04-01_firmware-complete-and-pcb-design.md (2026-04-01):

# Pico W + DS18B20 + SDカード + Ambient をつなぎきった日、そしてPCB設計の思考メモ

**2026-04-01 / 太陽熱養生プロジェクト**

---

## やったこと

Raspberry Pi Pico W に DS18B20 温度センサーを7本つなぎ、SDカードに記録しながら Ambient にデータを飛ばす、という一連の流れを動作確認した。
ついでにPCB設計の仕様もほぼ固めた。

結論から言うと、**ファームウェアは動いた。ただし道のりがなかなか険しかった。**

---

## なぜやるか

太陽熱で地面を養生する農業実験で、土中の温度分布を記録したい。
中央・エッジ・深さ方向に合計7本のDS18B20を刺し、30分ごとにSDカードとクラウド（Ambient）の両方に記録する。

電源断でも記録が途切れないこと、現場に行かなくても温度がわかること、この2点がシステムの核。

---

## ハマったポイントと設計の意図

### 1. SDカードがマウントできない問題

最初、SDカードは何度やっても `timeout waiting for v2 card` か `no SD card` で失敗し続けた。

ブレッドボードの配線を疑い、GND接続を確認し、SDカードを変え、ライブラリを入れ直し……それでも失敗。

**原因は2つ重なっていた。**

ひとつは**Pico W の CYW43 WiFi チップが同じ3.3Vレールを共有している**こと。WiFi が動いているとき3.3Vが2.9Vまで落ちていた（テスターで実測）。SDカードの初期化には安定した3.3Vが必要で、これに耐えられなかった。

もうひとつは、もっと単純な話で**拡張ボードの端子台のネジが緩んでいた**。これで接触抵抗が上がり、さらに電圧が落ちていた。

**解決策はシーケンス制御。** `wifi_off()` を呼んでからSDをマウントする。送信のときだけ `wifi_on()` → 送信 → `wifi_off()` という流れにした。WiFiとSDカードが同時に電力を奪い合わない構成にすることで、安定した。

```
WiFi OFF → SD マウント → センサー読み取り → SD書き込み
→ WiFi ON → Ambient送信 → WiFi OFF → 30分待機
```

ソフトウェアで解決したが、PCBでは根本から直す予定（後述）。

---

### 2. センサーIDの管理方法

DS18B20は1-Wireで複数本を同一バスにつなげる。バスをスキャンすると64bitのROMコードが返ってくる。これをどう管理するか。

最初は config.py に直書きしようとしたが、3台のPicoそれぞれでファームウェアを書き換えるたびにIDを確認してコードを書き直す…これはミスが出る。

**SDカードに `sensor_map.json` を置く方法にした。**

```json
{
  "zone": "zone-a",
  "sensors": {
    "286a535200000016": "S1_center_10cm",
    "28983bc0000000c3": "S2_center_25cm",
    ...
  }
}
```

ファームウェアは起動時にSDカードからマッピングを読み込むだけ。Pico3台でファームウェアは共通、SDカードの中身だけ変える。これでヒューマンエラーのリスクが大きく下がった。

---

### 3. ピン配置の設計

GPIO のピン番号を決めるときに気づいたことがある。

Pico W の**物理ピン4〜10が連続している**：

| 物理ピン | GPIO | 用途 |
|---|---|---|
| 4 | GP2 | SD SCK |
| 5 | GP3 | SD MOSI |
| 6 | GP4 | SD MISO |
| 7 | GP5 | SD CS |
| 8 | GND | GND |
| 9 | GP6 | SD カード検出 |
| 10 | GP7 | DS18B20 1-Wire |

SDカードの4本SPI信号＋GND＋カード検出＋センサーバスが**7ピン連続で全部片側に集まる**。

PCBを作るとき、この7ピンをひとつのコネクタでまとめて引き出せる。配線が整理されて、作業ミスも減る。「なんとなくピンを決める」のではなく、**物理的なレイアウトから逆算してピンを決める**のが今回の設計のポイントだった。

---

## PCB設計の方針（次フェーズ）

動作確認が取れたのでPCBに入る。今回の電源設計は考えることが多かったのでまとめて書いておく。

---

### 電源設計① PicoのWiFiとSDカードを干渉させない

前述のSDカード問題の根本原因はここにある。

Pico W には3.3Vの出力ピン（3V3_OUT）があり、「センサー電源はここから取れる」と思いがちだ。実際そうしていた。**でもこれは罠だった。**

Pico W 内部では WiFi チップ（CYW43）がこの3.3Vレールを共有している。WiFi の送受信時に大きな電流を消費し、レール電圧が瞬間的に落ちる。SDカードもこのレールに繋いでいると、SDの初期化やアクセス中に電圧不足で止まる。

PCBでの根本解決は**3.3Vレールを分離すること**。

```
5V 入力
 ├─ Pico W の VSYS（5V直入れ）→ Pico内部LDOで3.3V生成（WiFi・MCU用）
 └─ MCP1703-3302（外部LDO）→ 3.3V → SDカード・DS18B20専用
```

WiFiが暴れても外部LDOの3.3Vは揺れない。ソフトウェアのシーケンス制御（wifi_off）は保険として残すが、電源で根本から断つ。

---

### 電源設計② 単一入力から3.3Vを生む：LDO選定

外部LDOで5V→3.3Vを作ることにした。最初に思い浮かぶのはAMS1117-3.3だが、今回は使えない。

理由はバックアップ電源の構成にある（後述）。電池バックアップ時、入力電圧が4.2Vまで落ちる。AMS1117はドロップアウト電圧が1.5Vなので、最低4.8Vないと3.3Vが出せない。4.2Vでは力不足だ。

**MCP1703-3302を選んだ。** ドロップアウト250mV。4.2V入力でも 4.2 - 0.25 = 3.95V > 3.3V、十分な余裕がある。

部品一個の選定にも理由がある。それを記録しておくのがこのプロジェクトの趣旨だ。

---

### 電源設計③ バックアップ電源：ダイオードORで瞬時切り替え

フィールドに設置するシステムなので、電源が落ちたとき記録が止まるのは困る。けが人が出るわけではないが、データの連続性は確保したい。

最初はリレーで切り替えることを考えた。でもリレーには**切り替え時間（5〜10ms）と接点の摩耗**がある。なんとなく気持ち悪い。

**ショットキーダイオードOR回路にした。**

```
主電源 5V ─────────────────────────────────┐
                                            ├──→ 5V バス → 各Pico へ
電池(単3×3本=4.5V)─[Schottky: 1N5819]────┘
```

ダイオードは「電圧の高い方から電流が流れる、低い方は逆バイアスで遮断される」という性質を持つ。主電源5V > 電池4.5Vなので、主電源が生きている間は電池側のダイオードが逆バイアスになり電流は流れない。主電源が落ちた瞬間、ダイオードが順バイアスに切り替わり電池から供給が始まる。**機械的な動作なし、遅延なし。**

この構成は上流電源ボックスに1セット置き、3台のPicoBox全体をまとめてバックアップする。

**電池は単3×3本（4.5V）** を選んだ。入手性が高く、交換が簡単。バックアップ持続時間は平均電流30mA（3台合計）として約80時間、3〜4日分。現場に毎日行く必要はない。

---

### 電源設計④ サージ対策

屋外設置なので、雷や電源ON/OFFのスパイクに対する保護が必要だ。

**TVSダイオード（P6KE6.8A等）を5V入力ラインとGND間に入れる。** TVSは過電圧が来たとき瞬時にクランプして後段の回路を保護する。ポリスイッチ（自動復帰ヒューズ）と組み合わせることで、過電流・過電圧の両方に対処できる。

DS18B20の信号線（1-Wire）にも100Ωの直列抵抗を入れる。静電気や誤配線でGPIOピンを壊さないための保護だ。実験環境でケーブルを抜き差しする機会が多いので、ここは省略しない。

---

### 電源設計⑤ 主電源断の検知

バックアップ電源で動き続けながら、「今バックアップ中だ」という情報を送れると便利だ。Picoがメンテナンスが必要なことを自分で知らせてくれる。

GPIOに分圧回路（10kΩ × 2）で主電源5Vを2.5Vに落として監視する。主電源が落ちると GPIO が LOW になり、ファームウェアがそれを検知してAmbientかMQTTにアラートを飛ばす仕組みだ。電池が残っているうちに通知が飛ぶ。

---

### 全体の電源構成まとめ

```
【上流電源ボックス（1台）】
  24V入力
  → TVSダイオード（サージ保護）
  → DC-DC 5V変換
  → 逆接防止ダイオード D1
  → 5V バス ─────────────────────────→ PicoBox A/B/C

  電池(単3×3本=4.5V)
  → Schottky D2（ORダイオード）
  → 5V バス（主電源断時のみ通電）

【PicoBox（3台 同一設計）】
  5V IN
  → ポリスイッチ（過電流保護）
  → VSYS（Pico W） ─ Pico内部LDO ─ WiFi/MCU用 3.3V
  → MCP1703-3302  ─ 外部 3.3V ─ SDカード・DS18B20・LED
  → GP_MON ← 分圧回路 ← 5V バス（主電源監視）
```

シンプルに見えて、各ブロックに理由がある。

---

## 結果・気づき

- ファームウェアは完成、30秒ごとにSD書き込みとAmbient送信が安定動作
- 電圧問題はソフトウェアで一時回避、PCBで根本解決予定
- 「ブレッドボードのネジが緩んでいた」という物理的な原因が意外と大きかった。**電圧をテスターで実測する習慣は大事**
- ピン番号は連続性を意識して選ぶと配線がきれいになる

---

## 次の問い

- PCBでLDOを分離すれば `wifi_off()` シーケンスは不要になるか？（なるはず、でも念のため残す）
- MCP1703-3302 は実際に 4.2V（電池バックアップ時）でも安定して3.3Vを出せるか？
- 上流電源ボックスのダイオードOR、実際の切り替え波形はどうなるか？（オシロで確認したい）
- 単3×3本のバックアップで実際何時間持つか？（実測したい）

---

## ログ

- 2026-04-01: Pico W + DS18B20（2本）+ SD + Ambient の end-to-end 動作確認完了
- 2026-04-01: センサー7本→GP7 1-Wire バスで全本動作確認
- 2026-04-01: CSVを横持ち形式（1行1タイムスタンプ）に変更
- 2026-04-01: GPIOピン割り当て確定（物理ピン4-10の7ピン連続）
- 2026-04-01: PCB仕様確定（PicoBox + 上流電源ボックス構成）

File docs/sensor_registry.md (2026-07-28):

# センサー台帳

最終更新: 2026-07-28

## ⚠ ラベルと実際の深さのずれ（2026-07-28 時点）

**ラベル名は変更していない**。Picoのファームを農場でしか書き換えられず、
書き換えるまで新旧ラベルが混在してグラフの系列が割れるため。
実態とのずれは HP ダッシュボードの表示側で補正している。

| DBラベル | 実際 | 対象 |
|---|---|---|
| `S1_center_10cm` | 中央 **15cm** | 全ゾーン（過去データも同じ） |
| `S4_edge_10cm` | 端部 **15cm** | 全ゾーン（過去データも同じ） |
| `S7_outdoor` | 土壌 **5cm**（2026-07-28 08:50 JST〜） | 区A・区Bのみ。区Cは外気温のまま |

- 5cm は BLOF公式の基準深さだが、途中からの計測で条件が揃わないため **参考値扱い**。積算温度の計算には含めない。
- 表示補正は `portfolio/hugo/content/projects/solar-heat-data/index.md` の `LABEL_NAMES` / `labelName()` / `SOIL_5CM_ZONES`。
- Grafana は補正していないため、パネル名・列名は `10cm` 表記のまま（実際は15cm）。
- 次回農場でファームを書き換える際にラベル自体を改名するなら、DBの既存レコードも同時に UPDATE すること。

## 設計変更（2026-04-02）
1-Wireバス方式（GP7共有）から**個別GPIO方式**（GP8〜GP14）に変更。
IDスキャン・sensor_map.json廃止。GPIOピン番号がそのまま位置情報になる。

## ファームウェア更新（2026-07-20）

筐体入れ替え・プローブ差し替えへの対応方式を変更。

| 変更前 | 変更後 |
|---|---|
| サーバー側 `ZONE_REMAP` / `LABEL_REMAP` で受信時に変換 | Pico の `config.py` に `ZONE` と `SENSOR_PINS` を正しく設定 |

各Picoが正しいゾーン名・正しいセンサーラベルで送信するため、サーバー側の変換は不要になった。
ウォッチドッグタイマー（8秒）も同時に追加。

---

## ユニット3 → 区A（標準区）【ZONE: zone-a】

config: `config_pico3.py`
プローブ入替: GP8⇔GP10（中央10cm⇔40cm）、GP12⇔GP13（端部25cm⇔40cm）

| GPIO | コネクタ | センサーNo. | config SENSOR_PINS | 実際の深さ |
|---|---|---|---|---|
| GP8  | J8 | No.2  | S3_center_40cm | 中央 40cm |
| GP9  | J7 | No.1  | S2_center_25cm | 中央 25cm |
| GP10 | J2 | No.21 | S1_center_10cm | 中央 10cm |
| GP11 | J3 | No.19 | S4_edge_10cm | 端部 10cm |
| GP12 | J4 | No.20 | S6_edge_40cm | 端部 40cm |
| GP13 | J5 | No.18 | S5_edge_25cm | 端部 25cm |
| GP14 | J6 | No.36 | S7_outdoor | 外気温 |

---

## ユニット2 → 区B（対照・菌なし）【ZONE: zone-b】

config: `config_pico2.py`
プローブ入替: GP8⇔GP10（中央10cm⇔40cm）

| GPIO | コネクタ | センサーNo. | config SENSOR_PINS | 実際の深さ |
|---|---|---|---|---|
| GP8  | J8 | No.12 | S3_center_40cm | 中央 40cm |
| GP9  | J7 | No.13 | S2_center_25cm | 中央 25cm |
| GP10 | J2 | No.14 | S1_center_10cm | 中央 10cm |
| GP11 | J3 | No.11 | S4_edge_10cm | 端部 10cm |
| GP12 | J4 | No.15 | S5_edge_25cm | 端部 25cm |
| GP13 | J5 | No.16 | S6_edge_40cm | 端部 40cm |
| GP14 | J6 | No.17 | S7_outdoor | 外気温 |

---

## ユニット1 → 区C（対照・ビニールなし）【ZONE: zone-c】

config: `config_pico1.py`
プローブ入替: なし（デフォルトのSENSOR_PINS使用）

| GPIO | コネクタ | センサーNo. | ラベル（デフォルト） | 実際の深さ | DS18B20 ID |
|---|---|---|---|---|---|
| GP8  | J8 | No.8  | S1_center_10cm | 中央 10cm | 28abe15800000069 |
| GP9  | J7 | No.7  | S2_center_25cm | 中央 25cm | 28674ec00000002a |
| GP10 | J2 | No.10 | S3_center_40cm | 中央 40cm | 28d8574600000056 |
| GP11 | J3 | No.3  | S4_edge_10cm | 端部 10cm | 2899fd3400000035 |
| GP12 | J4 | No.4  | S5_edge_25cm | 端部 25cm | 28ef213400000060 |
| GP13 | J5 | No.9  | S6_edge_40cm | 端部 40cm | 28e80f34000000bf |
| GP14 | J6 | No.6  | S7_outdoor | 外気温 | 2866a758000000c9 |

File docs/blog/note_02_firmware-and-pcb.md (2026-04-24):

# 畑に置ける温度センサーを自作した。回路設計の記録。

---

## 1. 何のために作ったか

太陽熱養生の実験で、土の中の温度を継続的に記録することが目的です。

実験の概要は[前の記事](https://note.com/nono399/n/ne2afba002e9d)に書いています。

メイン機能
3区画それぞれに温度センサーを7本刺して、30分ごとに自動記録します。
WiFiが届かなければSDカードに書き溜めて、復帰後にまとめて送信する。
これを3台作って同時に動かします。

市販の温度ロガーでも記録はできますが、複数区画を同時にクラウドへ飛ばして比較できるものは高価でした。

---

## 2. この回路が何をしているか

回路の中身を部品ごとに説明します。KiCADで描いた回路図のポイントを、できるだけ平易に書きます。

### DS18B20（温度センサー）

防水プローブ付きのデジタル温度センサーです。土に直接刺して使います。マイコンボードのピンに1本ずつ直結する構成にしました。センサー1本につきピン1本を使うシンプルな設計です。

### Raspberry Pi Pico W（マイコンボード）

回路の頭脳にあたる部分です。センサーの値を読み取り、SDカードに書き込み、WiFi経由でクラウドにデータを飛ばします。MicroPythonというプログラミング言語で動かしています。

### MCP1703（LDO：電圧調整IC）

5Vの入力から3.3Vを作る部品です。センサーとSDカード専用の電源として使います。Pico W内蔵のWiFiチップが電源を大きく揺らすため、外部で独立した3.3Vを用意する必要がありました（後述）。

### TVSダイオード（サージ保護）

雷や電源ON/OFFのスパイクから回路を守る部品です。過電圧が来た瞬間にクランプして、後段の回路へのダメージを防ぎます。屋外設置なので省略できない部品です。

### ポリスイッチ（自動復帰ヒューズ）

過電流が流れたとき自動的に電流を遮断し、原因が解消されると自動復帰します。一般的なヒューズと違い、切れたら交換という手間がありません。フィールドに設置するシステムには便利な部品です。

### 分圧回路（主電源監視）

抵抗2本で5V入力を約2.5Vに落として、マイコンのアナログ入力ピン（GP26）で監視します。主電源が落ちて電池に切り替わると、入力電圧が5Vから約4.2Vに下がるため、GP26の電圧も約2.5Vから約2.1Vに低下します。ファームウェアはこの電圧低下をADCで検知して、クラウドにアラートを飛ばします。電池が残っているうちに通知が届く仕組みです。

---

## 3. KiCADで回路図を描いた

回路が決まったら、KiCADという無償の回路CADで回路図を描き、基板レイアウトに落とし込みました。

KiCADの使い方そのものはここでは書きません。公式サイトからダウンロードできます。
→ [KiCad EDA](https://www.kicad.org/)

回路図が完成したらガーバーファイル（基板製造用データ）を出力して、JLCPCBというサービスに発注しました。5枚で$4.64（送料込み）でした。

---

## 4. 工夫したポイント

**WiFi用とSDカード・センサー用で電源を分離した**

Pico W内蔵のWiFiチップは動作中に電源電圧を大きく揺らします。SDカードとDS18B20は安定した3.3Vが必要なので、外部LDO（MCP1703）で独立した電源ラインを作りました。

**センサーを1本1本独立したピンに割り当てた**

複数センサーを1本の信号線にまとめる方式だと、センサーごとの固有IDを管理する手間が増えます。今回は7本のセンサーにGP8〜GP14を1対1で割り当てました。どのピンのセンサーが異常かが一目でわかり、ファームウェアもシンプルになります。

**電池バックアップの持ちを計算した**

単3電池3本（4.5V）をバックアップとして積んでいます。平均消費電流から計算すると3〜4日分。毎日畑に行かなくてよいラインを意識して選定しました。

---

## 5. 詰まったポイント

**SDカードがマウントできなかった**

最初、SDカードは何度やっても認識されませんでした。原因は2つ重なっていました。

ひとつはWiFiチップによる電源の揺れ。WiFi動作中に3.3Vが2.9Vまで落ちていることを、テスターで実測してはじめてわかりました。もうひとつは端子台のネジの緩みによる接触不良です。

電圧は実測するまで気づきませんでした。**テスターで測ることを最初からやっておけばよかった**、というのが正直な感想です。

ひとまずソフトウェアで回避しました。WiFiをオフにしてからSDをマウントし、送信のときだけWiFiをオンにする流れにしたところ安定しました。PCBでは電源分離で根本から解決しています。

```
WiFi OFF → SD マウント → センサー読み取り → SD書き込み
→ WiFi ON → クラウド送信 → WiFi OFF → 30分待機
```

---

## 6. 最後に

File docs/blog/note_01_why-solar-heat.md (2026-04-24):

# 太陽熱養生で地温は実際どうなるの？自作センサーで測ってみることにした。

---

ビニールを張る前に毎年思うんですよね。「これ、ちゃんと効いてるのかな」と。

雑草は減った気がする。土がふかふかになった気もする。でも「気がする」止まりで、数字で確かめたことは一度もありませんでした。

自宅に10aほどの菜園があります。ニンニクや玉ねぎなど、まぁほとんどほったらかしでも育ってくれる野菜を中心に作っているんですが、正直なところ収穫よりも**試して記録すること**に面白さを感じています。今年はその菜園で、太陽熱養生中のビニールの中を本気で計測してみることにしました。

---

## きっかけは雑草と、1冊の本

直接のきっかけは雑草対策でした。

太陽熱養生で雑草種子を熱で死滅させられれば、シーズン前の管理がぐっと楽になります。頭ではわかっていたんですが、「どの深さまで、何℃まで上がるのか」を実際に測ったことがなかったんですよね。

そんなときに読んだのがこの本です↓

**「BLOF理論で有機菜園　初めてでもうまくいくしくみ」**（三澤明久 著・小祝政明 監修）

太陽熱養生と微生物の組み合わせについて書かれていて、なるほどと思う内容が多かったです。この本の内容を実践しつつ、効果を自分で検証できれば面白いと思いました。

---

## 太陽熱養生とは（知ってる方は読み飛ばしてください）

夏場に畑をビニールフィルムで覆い、太陽熱で地温を意図的に高める農業技術です。

地温が40〜50℃以上になると、病原菌・雑草種子・土壌害虫が死滅または抑制されます。農薬を使わずに土をリセットできる手法として、有機農業の世界では広く使われています。

さらに有機物や微生物資材を事前に入れてから養生すると、ビニール下で発酵が起き、土の微生物構成が大きく変わるといいます。熱処理と発酵の組み合わせで、単なる殺菌以上の効果が期待できるとのことです。

---

## 何を知りたいか

今回の実験で確かめたいことは大きく4つあります。

### ① 地温はどこまで上がるか

深さ10cm・25cm・40cm、そして畝の中央とエッジで温度はどう違うのか。ビニールの端では熱が逃げると聞きますが、どの程度の差があるのか気になっています。

### ② 微生物を入れると温度の推移は変わるか

発酵熱の上乗せがあれば、温度に何らかの違いが出るかもしれません。出るかどうかも含めて確かめたいところです。

### ③ 雑草種子の死滅に必要な条件は満たせるか

「55℃を3日以上かつ積算温度800℃〜900℃」で多くの種子が死滅するとされていますが、自分の畑ではどうなのか。
（積算温度は日中最高温度の足し算です）

### ④ 土壌診断で養生前後の変化を追う

温度だけでは土の中で何が起きたかはわかりません。pH・EC・NPKを養生前後で計測して、温度データと合わせて「何が変わったか」を読み解く手がかりにするつもりです。

---

## 実験の設計

畑を3区画に分けて比較します。

| 区分 | 内容 |
|---|---|
| 区A（対照） | 太陽熱養生のみ |
| 区B（標準） | 養生 ＋ 有機物投入 |
| 区C（微生物） | 養生 ＋ 有機物 ＋ 納豆菌・乳酸菌・酵母菌 |

各区に温度センサーを7本刺します。深さは10cm・25cm・40cmの3段階、中央とエッジの2箇所、そして区外に外気温センサーを1本。30分ごとに自動で記録し続ける構成です。

センサーユニットは自作することにしました。Raspberry Pi Pico W（マイコンボード）にDS18B20という防水温度センサーをつないで、WiFi経由でリアルタイム確認できる構成にします。電子基板は自分で設計して発注済みです。これについては別の記事で詳しく書きます。

土壌診断は**ジャパンバイオファーム**（BLOF理論の監修者・小祝政明氏が主宰）に依頼する予定です。養生前・養生直後の2回、同じ機関で計測することで比較の精度を保ちます。

---

## スケジュール

| 時期 | 内容 |
|---|---|
| 梅雨前 | 土壌診断① |
| 梅雨明け（7月中旬〜） | ビニール被覆・養生開始 |
| 養生期間中 | 30分ごとに自動記録 |
| 養生終了直後 | 土壌診断② |

---

## 最後に

「太陽熱養生は効く」という話はたくさんあります。でも自分の畑の、自分の施工条件での数字はどこにもないんですよね。

規模や土質が違えば結果も変わります。だからこそ自分で測る意味があると思っています。

農薬を減らしたい、雑草管理を楽にしたい、土をよくしたいと考えている方に、この実験の記録が何か参考になれば嬉しいです。うまくいくかどうかもわからない実験ですが、データは正直に全部公開する予定です。

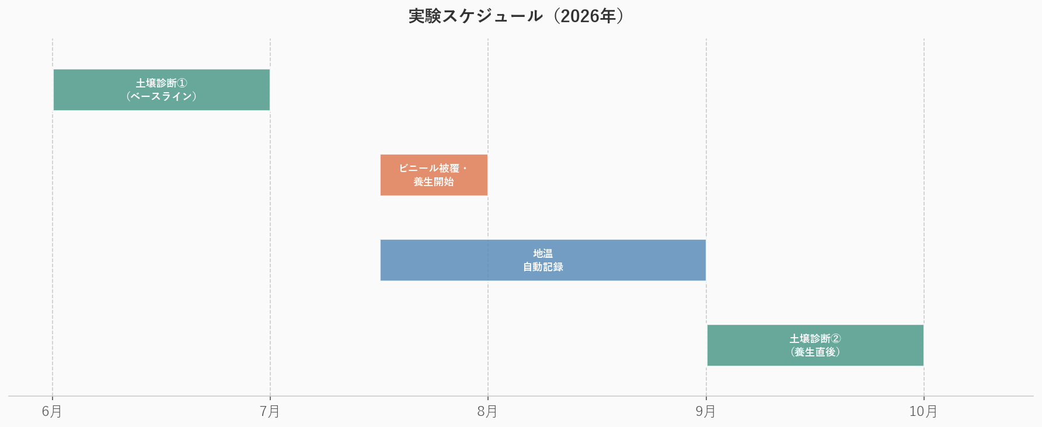
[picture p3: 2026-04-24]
docs/blog/schedule_gantt.png

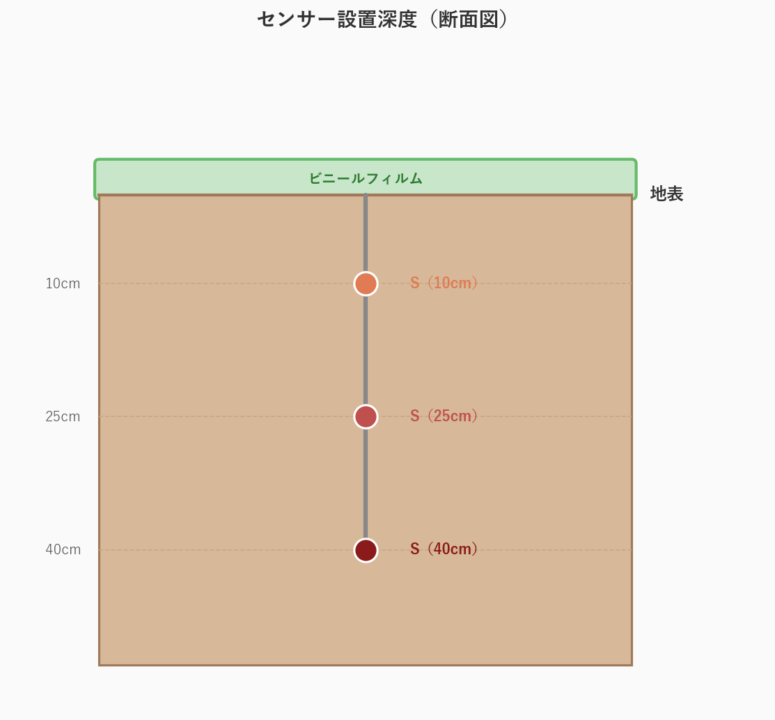
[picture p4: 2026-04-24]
docs/blog/fig_depth.png

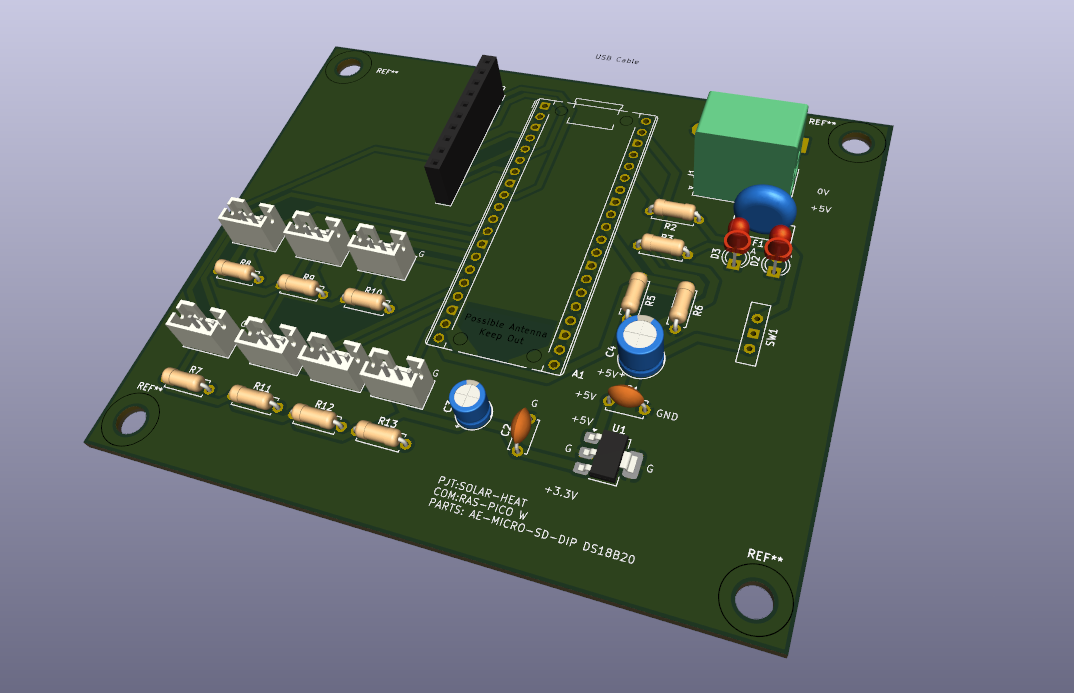
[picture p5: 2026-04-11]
docs/blog/fig_pcb_3d.png

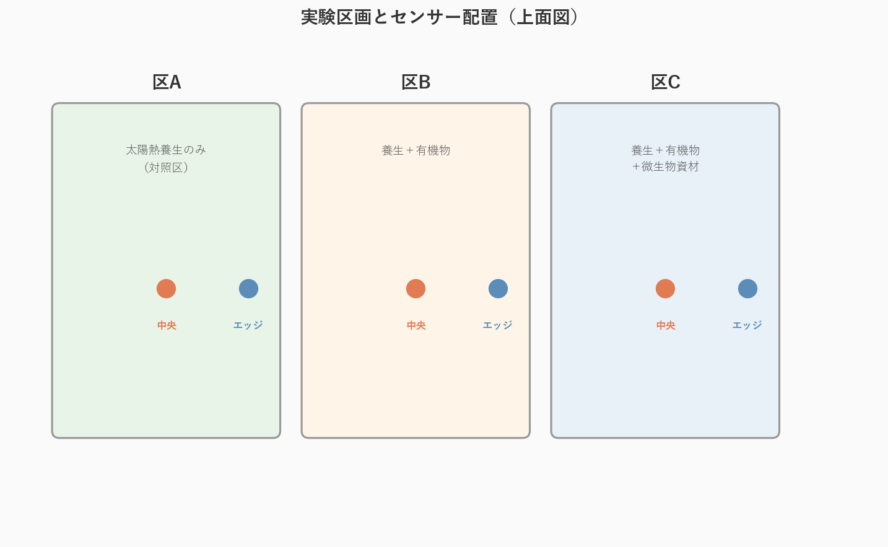
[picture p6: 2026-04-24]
docs/blog/fig_zones.png

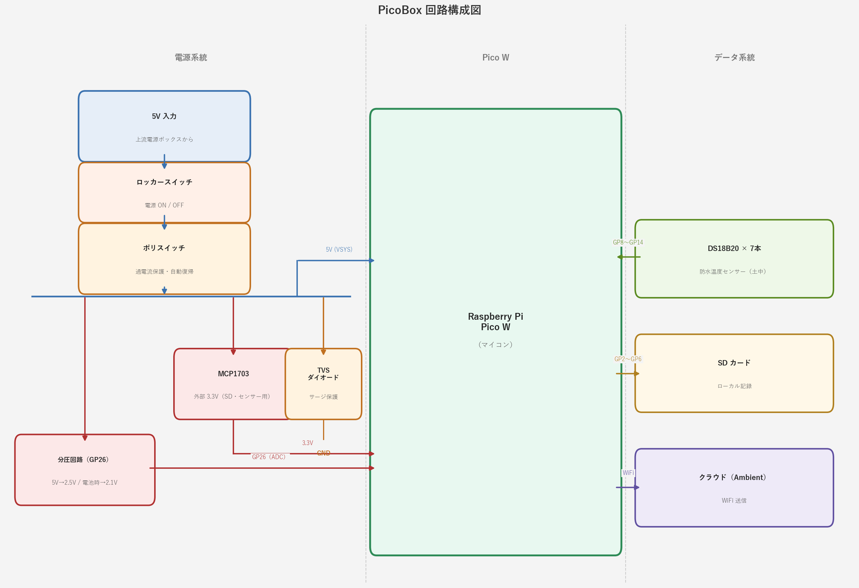
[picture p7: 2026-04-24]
docs/blog/fig_picobox_diagram.png

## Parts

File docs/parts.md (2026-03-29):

# 部材リスト - 太陽熱養生 温度測定プロジェクト

最終更新: 2026-03-29

---

## システム全体構成

```
【屋内】
AC100V
  ↓
漏電遮断器（三菱 NV50-KC 15A 30mA）
  ↓
Meanwell LRS-150-24（100V→24V 6.5A）
  ↓
DCヒューズ（3A）
  ↓
SPD-A（サージ保護）
  ↓
────── 屋外送電ライン 30m ──────
  ↓
SPD-B（サージ保護 ※畑アース棒接続）　← 未調達
  ↓
DC-DC コンバータ（24V→5V 5A）　← 未調達
  ↓
DCヒューズ（2A）
  ↓
────── 個別供給ライン 10m × 3 ──────
  ↓
【PicoBOX】× 3台（区A / 区B / 区C）
  Pico Unit 入力保護:
    ショットキーダイオード（逆接防止）　← 未調達
    ポリスイッチ 500mA（自動復帰ヒューズ）　← 未調達
    TVSダイオード（5V）+ 電解コンデンサ（10V 1000uF）　← 未調達
    LDOレギュレータ（5V→3.3V）　← 未調達
  ↓
  Pico W + SDカード + DS18B20 × 6本（GP21:中央3深度 / GP22:エッジ3深度）
```

---

## 試験区・センサー配置（testplan より）

| 区 | 内容 | 計測地点 | 深度 | センサー数 | Pico台 |
|---|---|---|---|---|---|
| 区A | 対照区（無処理） | 中央・エッジ | 10/25/40cm | 6本 | 1台 |
| 区B | 標準養生（透明フィルムのみ） | 中央・エッジ | 10/25/40cm | 6本 | 1台 |
| 区C | 微生物養生（資材+フィルム） | 中央・エッジ | 10/25/40cm | 6本 | 1台 |
| 外気温 | ― | ― | ― | 1本 | 区Aに同居 |
| **合計** | | | | **19本** | **3台** |

---

## 調達済み部材

### Picoサイド

| 部材 | 型番/仕様 | 数量 | 備考 |
|---|---|---|---|
| Raspberry Pi Pico W | RP2040 + WiFi | 1（要3台） | あと2台不足 |
| ブレイクアウトボード | Freenove 端子ブロックシールド | 1（要3台） | GPIO LED付き |
| 温度センサー | DS18B20 防水プローブ 3m | 5本（要19本） | **あと14本不足** |
| microSD カード | Kioxia 32GB UHS-I Class10 | 1（要3枚） | あと2枚不足 |
| SDカードリーダー | 秋月 105488 DIP化キット | 1（要3個） | SPI接続 |

### 電源サイド

| 部材 | 型番/仕様 | 数量 | 備考 |
|---|---|---|---|
| 漏電遮断器 | 三菱 NV50-KC 2P 15A 30mA | 1 | ✅ |
| 100V→24V PSU | Meanwell LRS-150-24 156W 24V 6.5A | 1 | ✅ |
| サージ保護（SPD-A） | DC24V用 | 1 | ✅ 屋内側 |
| ヒューズホルダ+ヒューズ | 5×20mm インライン | 1式 | ✅ 3A・2A 使用予定 |
| 防水ボックス | 220×170×110mm IP67 | 1（要複数） | 電源BOX・PicoBOX兼用 |

---

## 未調達部材

| 部材 | 仕様 | 優先度 | 備考 |
|---|---|---|---|
| DS18B20 追加 | 防水プローブ 3m | **最高** | あと14本（5本パック×3） |
| Pico W 追加 | RP2040 + WiFi | **最高** | あと2台 |
| SDカード 追加 | 32GB Class10 | 高 | あと2枚 |
| SDカードリーダー 追加 | 秋月 105488 | 高 | あと2個 |
| DC-DC コンバータ | 24V→5V 5A（25W）| **最高** | 中継BOX用。候補: Meanwell SD-25C-5 または同等品 |
| SPD-B | DC24V用（畑アース棒接続） | 高 | 屋外側サージ保護 |
| ショットキーダイオード | 逆接防止用 | 中 | Pico Unit保護回路 |
| ポリスイッチ | 500mA 自動復帰 | 中 | Pico Unit保護回路 |
| TVSダイオード | 5V用 | 中 | Pico Unit保護回路 |
| 電解コンデンサ | 10V 1000uF | 中 | Pico Unit保護回路 |
| LDOレギュレータ | 5V→3.3V | 中 | Pico Unit保護回路 |
| 防水ボックス 追加 | IP67 | 中 | PicoBOX×3 + 中継BOX |

---

## 未確定事項

- [ ] 送電ライン距離：購入時の想定は20m、power_planは30m → どちらが正しいか確認
- [ ] モバイルルーター（楽天）でUSB 5V給電できるか動作確認
- [ ] DC-DCコンバータ発注（Meanwell SD-25C-5 または同等品）
- [ ] Pico Unit保護回路：自作基板 or ユニバーサル基板で実装
- [ ] 送電ライン距離：20m か 30m か実測して確認

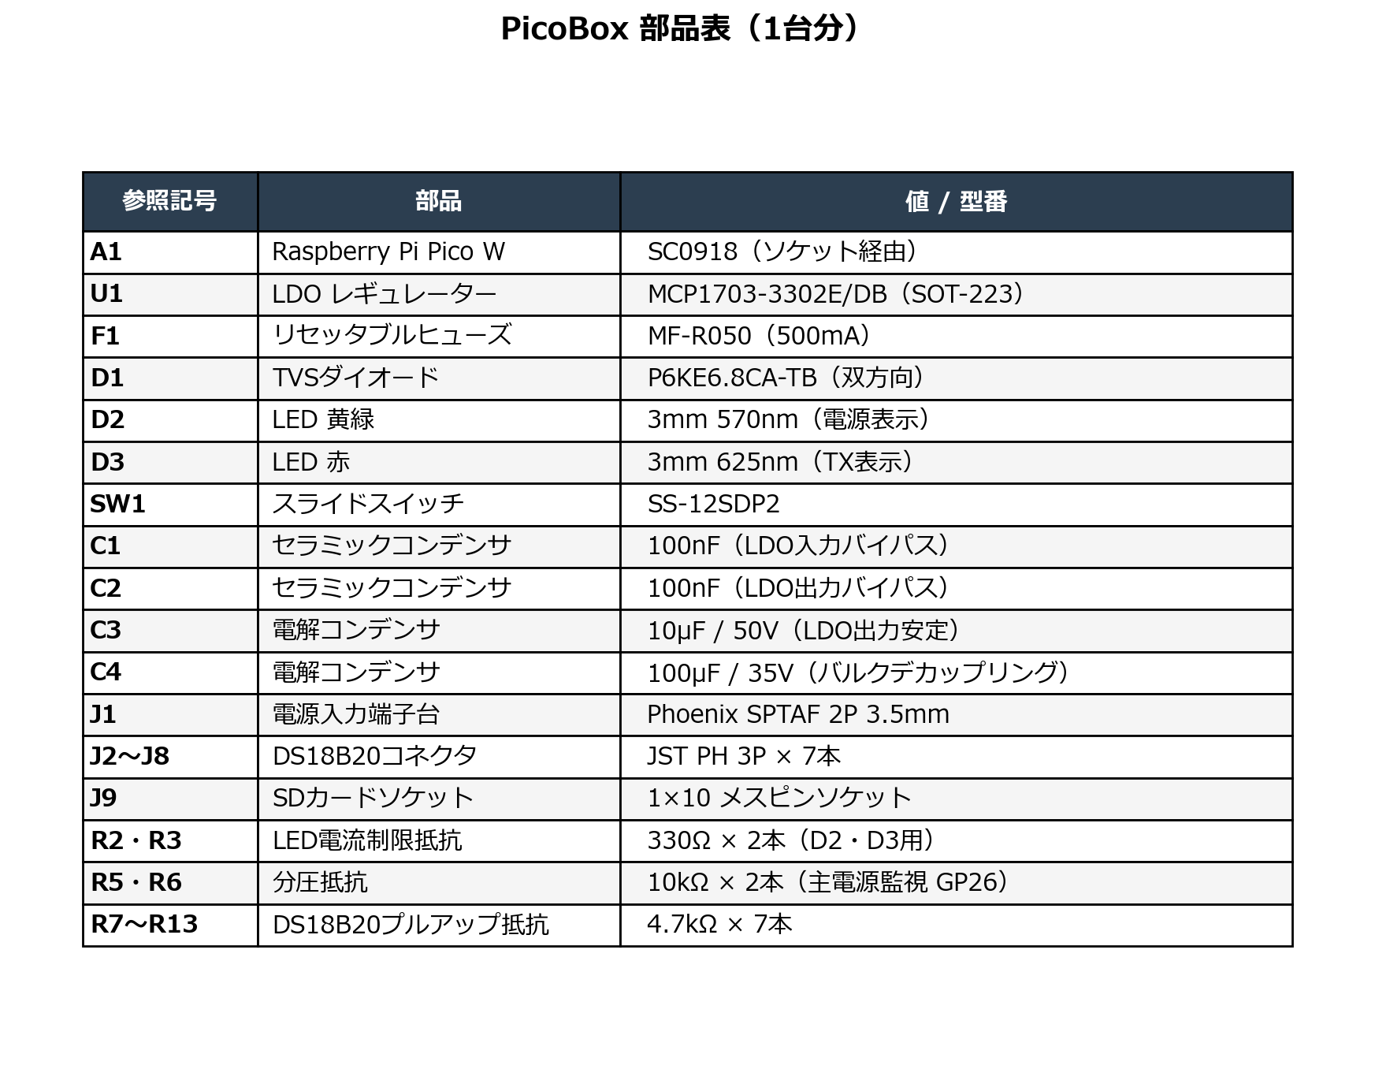
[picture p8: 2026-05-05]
docs/blog/fig_parts_table.png

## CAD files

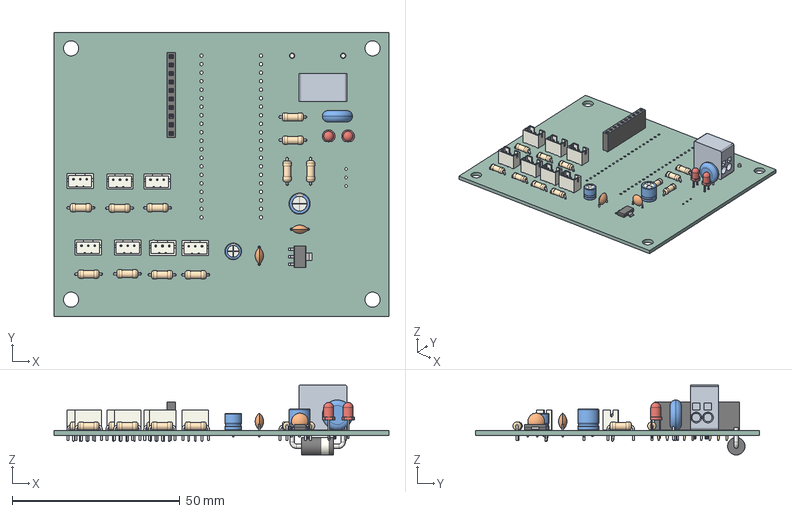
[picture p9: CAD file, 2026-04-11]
kicad/picobox/picobox/picobox.step
100.0 x 84.9 x 20.9 mm
R_Axial_DIN0207_L6.3mm_D2.5mm_P7.62mm_Horizontal x 11
JST_PH_B3B-PH-K_1x03_P2.00mm_Vertical x 7
PinSocket_1x10_P2.54mm_Vertical
picobox 1.11.1
LED_D3.0mm x 2
C_Disc_D5.0mm_W2.5mm_P5.00mm x 2
CP_Radial_D6.3mm_P2.50mm
CP_Radial_D5.0mm_P2.00mm
RV_Disc_D9mm_W3.4mm_P5mm
SOT-223
D_DO-201AD_P15.24mm_Horizontal
picobox_PCB

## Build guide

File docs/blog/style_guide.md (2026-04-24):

# 文章スタイルガイド

野々山昭太のnote記事における文章のニュアンス・語り口調の基準。
1本目の最終稿（2026-04）を正解として抽出。

---

## 基本の文末

**ベースは丁寧体（です・ます）**

```
✅ 「実際に測ったことがなかったです。」
✅ 「なるほどと思う内容が多かったです。」
✅ 「確かめたいところです。」
```

---

## 避ける表現

**「〜なんですよね」は使わない**

UEPON風の語り口として候補に上がるが、このブログには合わない。
読者に対して馴れ馴れしくなりすぎる。

```
❌ 「実際に測ったことがなかったんですよね。」
✅ 「実際に測ったことがなかったです。」

❌ 「だからこそ自分で測る意味があるんですよね。」
✅ 「だからこそ自分で測る意味があると思っています。」
```

---

## 感情・本音の出しかた

**「最後に」や「なぜやるか」など、個人的な部分では文体を崩してよい。**

少し荒削りで、整えすぎていない文章のほうが誠実さが伝わる。

```
✅「自分の畑の、自分の施工条件での数字はどこにもないんで
   ほんとに効いてるのか温度があがってるのかってわからんもんです。」

✅「規模や土質が違えば結果も変わるのかなと思うと、
   自分で測る意味があるんでしょう。」
```

ポイント：
- 「〜ないんで」「わからんもんです」「〜のかなと思うと」など口語を混ぜる
- 文を整えすぎない。少し流れるくらいがちょうどいい
- ただし本文中（説明・設計部分）では使わない。締めや動機の部分だけ

---

## 断言と保留のバランス

**事実には断言、効果・推測には保留**

```
✅「地温が40〜50℃以上になると、病原菌が死滅または抑制されます。」（事実）
✅「発酵熱の上乗せがあれば、温度に何らかの違いが出るかもしれません。」（推測）
✅「違いが出るかどうかも含めて確かめたいところです。」（保留）
```

「かもしれません」「〜とされています」「〜とのことです」を適切に使って
言い切らない誠実さを保つ。

---

## テクニカル用語の扱い

農家・農業系読者を想定。専門用語は使うが、初出時に一言添える。

```
✅「Raspberry Pi Pico W（マイコンボード）に」
✅「DS18B20という防水温度センサーを」
✅「（積算温度は日中最高温度の足し算です）」
```

カッコ書きで補足する形が読みやすい。

---

## リズム・文の長さ

短文と中文を交互に混ぜる。長文は避ける。

```
✅「雑草は減った気がする。土がふかふかになった気もする。
   でも「気がする」止まりで、数字で確かめたことは一度もありませんでした。」
```

段落は短めに。1段落3〜4文が目安。

---

## 見出しの書き方

- 体言止め or 疑問形
- 読み飛ばしOKの案内を入れてよい：「（知ってる方は読み飛ばしてください）」
- 番号付き小見出しは「① ② ③」形式

---

## アドバイス・提案をするとき

**忖度なしで答える。**

読者（野々山）が「これどう思う？」と聞いたとき、遠慮して曖昧にしない。
「やっても意味が薄い」「今は不要」「別の方法がいい」と思ったら、そう言う。

理由を添えて、代替案があれば提示する。最終判断は本人がする。

```
✅「ガーバー単体を公開しても、うれしい人はほぼいないです。理由は〜」
❌「公開するのも一つの選択肢かもしれませんね」
```

---

## 総括

| 項目 | 方針 |
|---|---|
| 基本文末 | です・ます |
| 「〜なんですよね」 | 使わない |
| 感情・本音パート | 口語OK・整えすぎない |
| 推測・効果の表現 | 保留表現で誠実に |
| 専門用語 | 初出はカッコで補足 |
| 文の長さ | 短〜中文、長文は避ける |

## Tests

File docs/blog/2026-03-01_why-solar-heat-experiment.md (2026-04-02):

# 太陽熱養生と微生物で、土をつくる実験をはじめる

**2026-03 / 太陽熱養生プロジェクト 試験計画**

---

## 太陽熱養生とは

太陽熱養生（たいようねつようじょう）とは、夏場に畑の地面を透明または黒のビニールフィルムで覆い、太陽熱で地温を意図的に高める農業技術だ。

地温が40〜50℃以上に上がると、病原菌・雑草種子・土壌害虫が死滅または抑制される。農薬を使わずに土をリセットできる手法として有機農業の世界では広く使われている。

さらに有機物や微生物資材を事前に土に入れてから養生すると、土中で発酵が起き、微生物叢の構成が大きく変わるという。熱処理と発酵処理を組み合わせることで、単なる殺菌以上の効果が得られる可能性がある。

---

## なぜこの実験をするか

自宅に10aほどの家庭菜園がある。ニンニクや玉ねぎなど手間のかからないものを中心に育てているが、どちらかというと**実験場として使っているイメージ**だ。生産よりも、試して記録することを目的にしている。

今回この実験を始める直接のきっかけは**雑草対策**だ。太陽熱養生で雑草種子を熱処理してシーズン前の雑草を減らせるなら、その後の管理がぐっと楽になる。さらに、別途開発を進めている**自動除草ロボット**との組み合わせで、雑草管理の省力化を本格的に実現できるのではないかと考えている。太陽熱養生で抑えて、残った雑草をロボットが刈る。2つのプロジェクトが連携する構想だ。

きっかけのもうひとつはこの本を読んだことだ。

**「BLOF理論で有機菜園　初めてでもうまくいくしくみ」**（三澤明久 著・小祝政明 監修）

基本的なことが網羅的に書いてある。化学的なアプローチも含まれているが、太陽熱養生や微生物の効果については**体感によるところが大きい**という印象を受けた。数字で実証されていない部分が多い。ならば自分で計測して記録してみようと思った。

仕事でも農業と計測・自動化に関わっている。その視点を自分の畑の実験に持ち込むのは自然な流れだった。ただしここでの実験と発信はあくまで**個人の活動**であり、仕事の延長ではない。

---

## 何を知りたいか

1. **太陽熱養生で地温はどこまで上がるか？** 深さ・場所（中央・エッジ）によってどう違うか？
2. **微生物資材（納豆菌・乳酸菌・酵母菌）を入れると、地温の推移は変わるか？** 発酵熱の上乗せはあるか？
3. **雑草種子の死滅に必要な温度・時間は達成できるか？**
4. 体感ベースで語られてきた微生物効果を、数字で少しでも検証できるか？

---

## 微生物資材について

今回使う微生物は3種類。

**納豆菌（Bacillus subtilis natto）**
枯草菌の一種。高温（50〜60℃）でも生存できる耐熱性を持つ。土中の有機物を分解し、抗菌物質を産生して病原菌を抑制する。

**乳酸菌（Lactobacillus 属等）**
糖を乳酸に変えて環境を酸性化し、腐敗菌や病原菌の増殖を抑える。嫌気的な条件（ビニール被覆下）で活発に働く。

**酵母菌（Saccharomyces 等）**
有機物の発酵を助け、他の微生物が利用しやすい物質（アミノ酸・ビタミン類）を産生する。

これらをBLOF理論の記述を参考に培養・投入する予定だ。

---

## 試験区の設定

圃場を3区画に分けて比較する。

| 区 | 名称 | 処理内容 |
|---|---|---|
| 区A | 対照区 | 太陽熱養生のみ（有機物・微生物なし） |
| 区B | 標準養生区 | 太陽熱養生 ＋ 有機物投入 |
| 区C | 微生物養生区 | 太陽熱養生 ＋ 有機物 ＋ 納豆菌・乳酸菌・酵母菌 |

各区とも温度センサーを7本設置する。

| センサー | 位置 | 深さ |
|---|---|---|
| S1 | 中央 | 10cm |
| S2 | 中央 | 25cm |
| S3 | 中央 | 40cm |
| S4 | エッジ | 10cm |
| S5 | エッジ | 25cm |
| S6 | エッジ | 40cm |
| S7 | 区外 | 外気温（地表付近） |

中央とエッジ、浅い・深いの組み合わせで温度分布の全体像を把握する。S7との差を見ることで、ビニール被覆による昇温効果を定量化する。

---

## 土壌診断：養生前後の変化を数字で見る

温度の記録だけでなく、**養生によって土がどう変わったかを土壌診断で記録する**。

微生物の効果や有機物の分解は温度データには現れない。養生前後で土壌の状態を比較することで、「温度が上がった」だけでなく「土の中で何が起きたか」を追える。

### 診断タイミング

| タイミング | 目的 |
|---|---|
| 養生開始前 | ベースライン（各区の初期状態を記録） |
| 養生終了直後 | 熱処理・発酵による変化を確認 |
| 作付け前（1〜2ヶ月後） | 土壌の回復・安定を確認 |

### 診断項目（予定）

| 項目 | 意味 |
|---|---|
| pH | 酸性・アルカリ性。微生物活性や養分の溶けやすさに影響 |
| EC（電気伝導度） | 土中の塩類濃度。施肥量の目安 |
| 窒素（N）・リン酸（P）・カリ（K） | 主要3要素。BLOF理論では特に重視 |
| 有機物含量 | 土の保水性・微生物のエサ |

3区を同じ条件で診断し、区A（対照）との差を見ることで微生物資材・有機物の効果を評価する。

> 測定は**ジャパンバイオファーム**に依頼する予定。本書の監修者・小祝政明氏が主宰する機関で、BLOF理論に基づいた土壌診断を行っている。理論と診断機関を揃えることで、結果の解釈に一貫性を持たせられる。簡易キットでは再現性・精度に限界があるため、3区の比較に耐えるデータを取るには専門機関への依頼が妥当と判断した。

---

## スケジュール

| 時期 | 作業 |
|---|---|
| 養生開始前 | **土壌診断①**（ベースライン） |
| 梅雨明け（7月中旬〜） | ビニール被覆・養生開始 |
| 養生期間中 | 30分ごとに地温を連続記録 |
| 養生終了直後 | **土壌診断②**（養生効果の確認） |
| 作付け前 | **土壌診断③**（回復・安定の確認） |
| 養生終了後 | データ整理・考察 |

---

## 計測デバイスについて

温度センサー（DS18B20）7本の値を30分ごとに記録し、クラウド（Ambient）とSDカードの両方に保存するシステムを自作する。Raspberry Pi Pico W を使い、WiFi経由でリアルタイム確認ができる構成だ。

次の記事からデバイスの製作記録に入る。

---

## 次の問い

- 太陽熱養生中の地温は実際に何度まで上がるか？
- 微生物を入れた区とそうでない区で、温度推移・土壌診断結果に違いは出るか？
- 深さ40cmまで熱は届くか？
- 専門機関の診断結果はどう読むか？3区の差を有意に判断できるか？
- 雑草の発生率は養生区と非養生区で実際に変わるか？
- 除草ロボットとの組み合わせで管理工数はどこまで減らせるか？

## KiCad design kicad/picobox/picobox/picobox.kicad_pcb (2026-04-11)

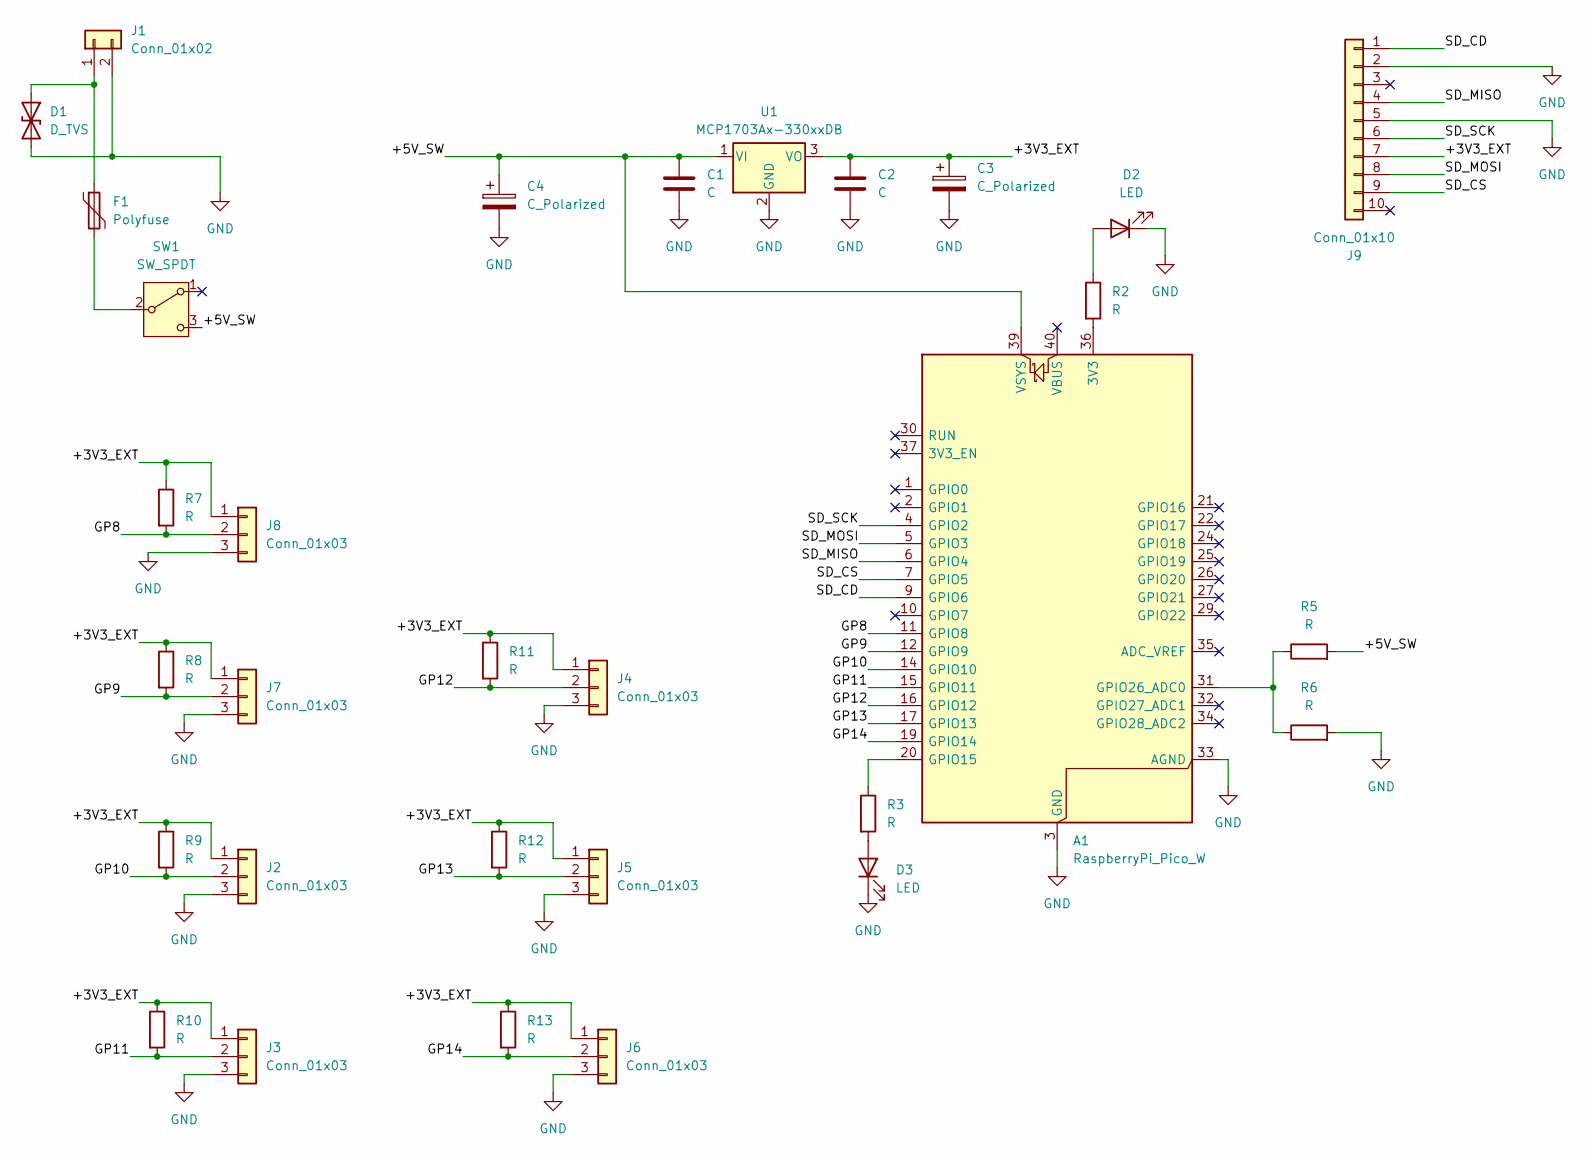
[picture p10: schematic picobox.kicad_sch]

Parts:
A1: RaspberryPi_Pico_W; RaspberryPi_Pico_Common_THT
C1, C2: C; C_Disc_D5.0mm_W2.5mm_P5.00mm
C3: C_Polarized; CP_Radial_D5.0mm_P2.00mm
C4: C_Polarized; CP_Radial_D6.3mm_P2.50mm
D1: D_TVS; D_DO-201AD_P15.24mm_Horizontal
D2, D3: LED; LED_D3.0mm
F1: Polyfuse; RV_Disc_D9mm_W3.4mm_P5mm
J1: Conn_01x02; PhoenixContact_SPT_1.5_2-H-3.5_1x02_P3.5mm_Horizontal
J2, J3, J4, J5, J6, J7, J8: Conn_01x03; JST_PH_B3B-PH-K_1x03_P2.00mm_Vertical
J9: Conn_01x10; PinSocket_1x10_P2.54mm_Vertical
R2, R3, R5, R6, R7, R8, R9, R10, R11, R12, R13: R; R_Axial_DIN0207_L6.3mm_D2.5mm_P7.62mm_Horizontal
SW1: SW_SPDT; SW_Slide-03_Wuerth-WS-SLTV_10x2.5x6.4_P2.54mm
U1: MCP1703Ax-330xxDB; SOT-223-3_TabPin2

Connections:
/+3V3_EXT: C2.1, C3.1, J2.1, J3.1, J4.1, J5.1, J6.1, J7.1, J8.1, J9.7, R7.1, R8.1, R9.1, R10.1, R11.1, R12.1, R13.1, U1.3 (VO)
/+5V_SW: A1.39 (VSYS), C1.1, C4.1, R5.2, SW1.3 (C), U1.1 (VI)
/GP8: A1.11 (GPIO8), J8.2, R7.2
/GP9: A1.12 (GPIO9), J7.2, R8.2
/GP10: A1.14 (GPIO10), J2.2, R9.2
/GP11: A1.15 (GPIO11), J3.2, R10.2
/GP12: A1.16 (GPIO12), J4.2, R11.2
/GP13: A1.17 (GPIO13), J5.2, R12.2
/GP14: A1.19 (GPIO14), J6.2, R13.2
/SD_CD: A1.9 (GPIO6), J9.1
/SD_CS: A1.7 (GPIO5), J9.9
/SD_MISO: A1.6 (GPIO4), J9.4
/SD_MOSI: A1.5 (GPIO3), J9.8
/SD_SCK: A1.4 (GPIO2), J9.6
GND: A1.3 (GND), A1.8 (GND), A1.13 (GND), A1.18 (GND), A1.23 (GND), A1.28 (GND), A1.33 (AGND), A1.38 (GND), C1.2, C2.2, C3.2, C4.2, D1.2 (A2), D2.1 (K), D3.1 (K), J1.2, J2.3, J3.3, J4.3, J5.3, J6.3, J7.3, J8.3, J9.2, J9.5, R6.2, U1.2 (GND)
unnamed: A1.36 (3V3), R2.2
unnamed: A1.20 (GPIO15), R3.1
unnamed: A1.31 (GPIO26_ADC0), R5.1, R6.1
unnamed: D1.1 (A1), F1.1, J1.1
unnamed: D2.2 (A), R2.1
unnamed: D3.2 (A), R3.2
unnamed: F1.2, SW1.2 (B)

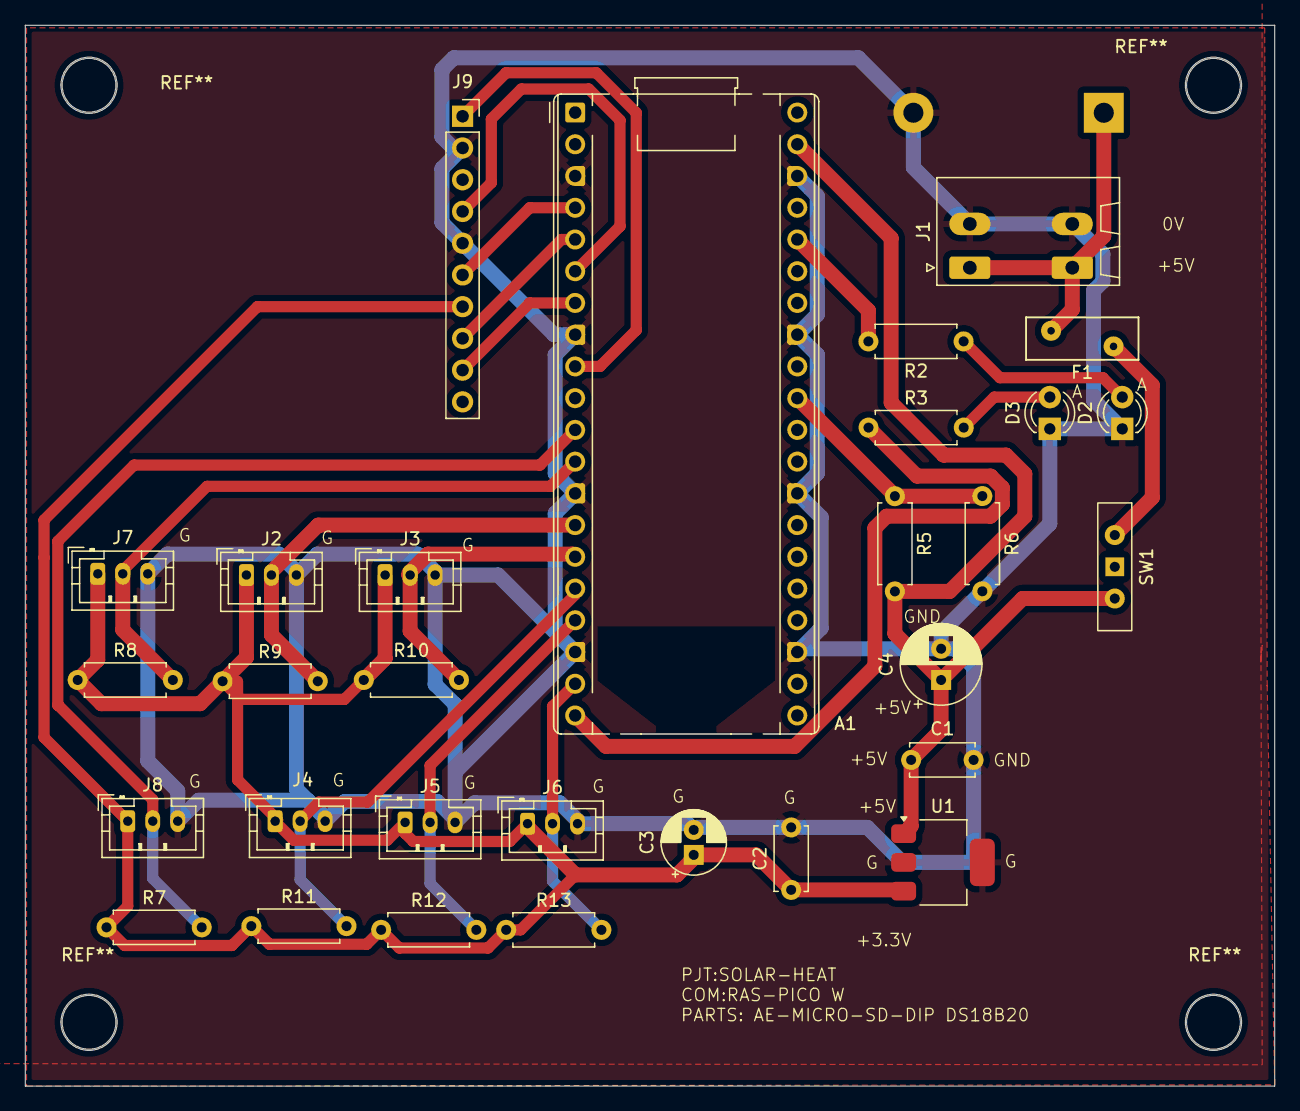
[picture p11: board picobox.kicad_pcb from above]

Board: 2 copper layers, 100.0 x 84.9 mm, 31 parts (1 on the bottom side), 22 nets.

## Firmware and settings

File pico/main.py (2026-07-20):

"""
Raspberry Pi Pico W - 太陽熱養生 温度ロガー
機能: DS18B20 個別GPIO / SDカード記録 / Ambient送信 / MQTT送信 / ヘルス監視

各センサーは専用GPIOピンに直結（1-Wire バス方式廃止）
ゾーン名は config.py の ZONE 変数で管理

赤LED 表示パターン:
  消灯       正常
  常時点灯   電源異常（bus_v < 4.0V）
  低速点滅   SD異常（マウント失敗・書き込み失敗・カード未挿入）
  高速点滅   電源異常 + SD異常 同時発生
"""
import machine
import onewire
import ds18x20
import time
import sdcard
import os
import network
import ntptime
import ujson
import config

try:
    from umqtt.simple import MQTTClient
    MQTT_AVAILABLE = True
except ImportError:
    MQTT_AVAILABLE = False

# --- ピン定義 ---
PIN_SD_SCK    = 2
PIN_SD_MOSI   = 3
PIN_SD_MISO   = 4
PIN_SD_CS     = 5
PIN_SD_DETECT = 6    # カード検出（挿入時 LOW）
PIN_LED_TX    = 15   # 送信／ステータスLED
PIN_POWER_MON = 26   # 主電源監視 ADC（10kΩ/10kΩ分圧）

# 5V入力時: GP26 = 2.5V。閾値4.0V入力 → GP26 = 2.0V
POWER_THRESHOLD_V = 4.0

# DS18B20 個別GPIO（config.py で上書き可能）
SENSOR_PINS = getattr(config, "SENSOR_PINS", {
    8:  "S1_center_10cm",
    9:  "S2_center_25cm",
    10: "S3_center_40cm",
    11: "S4_edge_10cm",
    12: "S5_edge_25cm",
    13: "S6_edge_40cm",
    14: "S7_outdoor",
})

INTERVAL_SEC = 1800  # 計測間隔（秒）= 30分
WDT_TIMEOUT  = 8000  # ウォッチドッグ（ms）
TIME_OFFSET  = 9 * 3600  # JST (UTC+9)

led_tx    = machine.Pin(PIN_LED_TX, machine.Pin.OUT)
sd_detect = machine.Pin(PIN_SD_DETECT, machine.Pin.IN, machine.Pin.PULL_UP)
adc_power = machine.ADC(PIN_POWER_MON)

# --- グローバル状態 ---
sd_status = "unknown"           # "ok" / "no_card" / "mount_failed" / "write_failed" / "ok_after_remount"
sd_mounted = False
last_wifi_attempts = 0
boot_time = None  # NTP同期後に設定（同期前はNoneのまま）


# --- LED ステートマシン（Timer駆動で連続点滅） ---
LED_OFF        = 0
LED_SOLID      = 1   # 電源異常
LED_SLOW_BLINK = 2   # SD異常（1Hz）
LED_FAST_BLINK = 3   # 両方同時（5Hz）

_led_state = LED_OFF
_led_counter = 0

# センサー状態: {label: True(正常) / False(未検出・読み取りエラー)}
sensor_status = {}


def _led_tick(t):
    global _led_counter
    if _led_state == LED_OFF:
        return  # Timerは触らない（手動blink可）
    if _led_state == LED_SOLID:
        led_tx.on()
        return
    _led_counter = (_led_counter + 1) % 10
    if _led_state == LED_SLOW_BLINK:
        led_tx.value(1 if _led_counter < 5 else 0)
    elif _led_state == LED_FAST_BLINK:
        led_tx.value(_led_counter % 2)


_led_timer = machine.Timer()
_led_timer.init(period=100, mode=machine.Timer.PERIODIC, callback=_led_tick)


def set_led_state(power_alert, sd_alert):
    """電源・SDのアラート状態からLED状態を決定"""
    global _led_state, _led_counter
    if power_alert and sd_alert:
        new_state = LED_FAST_BLINK
    elif power_alert:
        new_state = LED_SOLID
    elif sd_alert:
        new_state = LED_SLOW_BLINK
    else:
        new_state = LED_OFF
    if new_state != _led_state:
        _led_state = new_state
        _led_counter = 0
        if new_state == LED_OFF:
            led_tx.off()


def blink_tx(n=2):
    """送信成功のブリンク。アラート中はスキップ"""
    if _led_state != LED_OFF:
        return
    for _ in range(n):
        led_tx.on()
        time.sleep_ms(150)
        led_tx.off()
        time.sleep_ms(150)


# --- SDカード ---
def is_sd_inserted():
    return sd_detect.value() == 0  # LOW = 挿入済み


def mount_sd():
    """SDをマウント。成功でTrue、失敗でFalse（例外を投げない）"""
    global sd_mounted, sd_status
    if not is_sd_inserted():
        sd_status = "no_card"
        sd_mounted = False
        return False
    try:
        spi = machine.SPI(0,
            sck=machine.Pin(PIN_SD_SCK),
            mosi=machine.Pin(PIN_SD_MOSI),
            miso=machine.Pin(PIN_SD_MISO))
        sd = sdcard.SDCard(spi, machine.Pin(PIN_SD_CS))
        os.mount(os.VfsFat(sd), "/sd")
        sd_mounted = True
        sd_status = "ok"
        return True
    except Exception as e:
        print("[SD] mount failed:", e)
        sd_status = "mount_failed"
        sd_mounted = False
        return False


def umount_sd():
    global sd_mounted
    try:
        os.umount("/sd")
    except Exception:
        pass
    sd_mounted = False


def _exists(path):
    try:
        os.stat(path)
        return True
    except:
        return False


def _write_csv(ts, data):
    zone   = config.ZONE
    fname  = "/sd/{}_log_{:04d}{:02d}{:02d}.csv".format(zone, ts[0], ts[1], ts[2])
    labels = [SENSOR_PINS[p] for p in sorted(SENSOR_PINS)]
    need_header = not _exists(fname)
    with open(fname, "a") as f:
        if need_header:
            f.write("datetime," + ",".join(labels) + "\n")
        dt  = "{:04d}-{:02d}-{:02d} {:02d}:{:02d}:{:02d}".format(*ts[:6])
        row = [dt] + ["{:.2f}".format(data[l]) if l in data else "" for l in labels]
        f.write(",".join(row) + "\n")
    return fname


def log_to_sd_with_recovery(ts, data):
    """書き込み失敗時に再マウント試行。状態を sd_status に反映"""
    global sd_status, sd_mounted

    # 1. カード検出チェック
    if not is_sd_inserted():
        sd_status = "no_card"
        sd_mounted = False
        print("[SD] no card detected")
        return False

    # 2. マウントされていなければマウント試行
    if not sd_mounted:
        if not mount_sd():
            return False

    # 3. 書き込み試行
    try:
        fname = _write_csv(ts, data)
        sd_status = "ok"
        print("[SD] OK -> {}".format(fname))
        return True
    except Exception as e:
        print("[SD] write failed:", e)
        # 4. 再マウントしてもう一度
        umount_sd()
        if mount_sd():
            try:
                fname = _write_csv(ts, data)
                sd_status = "ok_after_remount"
                print("[SD] OK after remount -> {}".format(fname))
                return True
            except Exception as e2:
                print("[SD] write failed after remount:", e2)
                sd_status = "write_failed"
                sd_mounted = False
                return False
        sd_status = "write_failed"
        return False


# --- WiFi ---
def wifi_off():
    wlan = network.WLAN(network.STA_IF)
    wlan.active(False)


def connect_wifi():
    """WiFiを一度OFFしてから接続。失敗時は1回リトライ（最大2回試行）"""
    global last_wifi_attempts
    for attempt in range(1, 3):
        last_wifi_attempts = attempt
        wlan = network.WLAN(network.STA_IF)
        wlan.active(False)
        time.sleep_ms(500)
        wlan.active(True)
        wlan.connect(config.WIFI_SSID, config.WIFI_PASSWORD)
        for _ in range(20):
            wdt.feed()
            if wlan.isconnected():
                print("[WiFi] connected (attempt {}):".format(attempt), wlan.ifconfig()[0])
                return True
            time.sleep(1)
        print("[WiFi] attempt {} timeout".format(attempt))
    print("[WiFi] ERROR: all attempts failed")
    return False


# --- NTP ---
def sync_ntp():
    global boot_time
    try:
        ntptime.settime()
        boot_time = time.time()  # NTP同期後に記録（uptime計算の基点）
        print("NTP synced (UTC)")
    except Exception as e:
        print("NTP error:", e)


def jst_time():
    return time.localtime(time.time() + TIME_OFFSET)


# --- センサー読み取り ---
def read_sensors():
    """全センサーを一括読み取り。sensor_status を毎サイクル更新する。
    True=正常, False=未検出またはエラー"""
    global sensor_status

    instances = {}
    for pin_num, label in SENSOR_PINS.items():
        try:
            ow   = onewire.OneWire(machine.Pin(pin_num))
            ds   = ds18x20.DS18X20(ow)
            roms = ds.scan()
            if not roms:
                print("[SENSOR] GP{} no sensor".format(pin_num))
                sensor_status[label] = False
                continue
            ds.convert_temp()
            instances[pin_num] = (ds, roms[0], label)
        except Exception as e:
            print("[SENSOR] GP{} scan error: {}".format(pin_num, e))
            sensor_status[label] = False

    time.sleep_ms(750)  # 全センサー変換完了待ち（1回のみ）

    results = {}
    for pin_num, (ds, rom, label) in instances.items():
        try:
            results[label] = ds.read_temp(rom)
            sensor_status[label] = True
        except Exception as e:
            print("[SENSOR] GP{} read error: {}".format(pin_num, e))
            sensor_status[label] = False
    return results


# --- Ambient ---
def send_ambient(data):
    try:
        import urequests
        labels  = [SENSOR_PINS[p] for p in sorted(SENSOR_PINS)]
        payload = {"writeKey": config.AMBIENT_WRITE_KEY}
        for i, label in enumerate(labels[:8]):
            if label in data:
                payload["d{}".format(i + 1)] = round(data[label], 2)
        url = "http://ambidata.io/api/v2/channels/{}/data".format(config.AMBIENT_CHANNEL_ID)
        res = urequests.post(url,
                             headers={"Content-Type": "application/json"},
                             data=ujson.dumps(payload))
        print("[Ambient] OK status={}".format(res.status_code))
        res.close()
        return True
    except Exception as e:
        print("[Ambient] ERROR:", e)
        return False


# --- MQTT ---
def send_mqtt(ts, data):
    if not MQTT_AVAILABLE:
        return False
    try:
        zone   = config.ZONE
        client = MQTTClient("pico_{}".format(zone), config.MQTT_BROKER, port=config.MQTT_PORT,
                            user=config.MQTT_USER, password=config.MQTT_PASS)
        client.connect()
        dt = "{:04d}-{:02d}-{:02d}T{:02d}:{:02d}:{:02d}".format(*ts[:6])
        for label, temp in data.items():
            topic   = "solar-heat/{}/{}".format(zone, label)
            payload = ujson.dumps({"time": dt, "temp": round(temp, 2)})
            client.publish(topic, payload)
        client.disconnect()
        print("[MQTT] OK -> {} topics".format(len(data)))
        return True
    except Exception as e:
        print("[MQTT] ERROR:", e)
        return False


def send_status(ts, bus_v):
    """デバイス自身のヘルス状態を送る。
    トピック: solar-heat/{zone}/status
    含む情報: SD状態, センサー正常/異常ラベル, 電源電圧, WiFi試行回数, 起動からの経過時間"""
    if not MQTT_AVAILABLE:
        return
    try:
        zone = config.ZONE
        client = MQTTClient("pico_{}_status".format(zone), config.MQTT_BROKER, port=config.MQTT_PORT,
                            user=config.MQTT_USER, password=config.MQTT_PASS)
        client.connect()
        dt = "{:04d}-{:02d}-{:02d}T{:02d}:{:02d}:{:02d}".format(*ts[:6])
        uptime_min = (time.time() - boot_time) // 60 if boot_time else -1
        ng_sensors = [l for l, ok in sensor_status.items() if not ok]
        payload = ujson.dumps({
            "time":         dt,
            "zone":         zone,
            "bus_v":        round(bus_v, 2),
            "sd_status":    sd_status,
            "sensors_ok":   len(sensor_status) - len(ng_sensors),
            "sensors_ng":   ng_sensors,
            "wifi_attempts": last_wifi_attempts,
            "uptime_min":   uptime_min,
        })
        client.publish("solar-heat/{}/status".format(zone), payload)
        client.disconnect()
        print("[Status] sd={} sensors_ng={} uptime={}min".format(
            sd_status, ng_sensors, uptime_min))
    except Exception as e:
        print("[Status] ERROR:", e)


# --- 電源監視 ---
def read_bus_voltage():
    adc_v = adc_power.read_u16() / 65535 * 3.3
    return adc_v * 2


def send_power_alert(bus_v):
    if not MQTT_AVAILABLE:
        return
    try:
        zone   = config.ZONE
        client = MQTTClient("pico_{}_alert".format(zone), config.MQTT_BROKER, port=config.MQTT_PORT,
                            user=config.MQTT_USER, password=config.MQTT_PASS)
        client.connect()
        payload = ujson.dumps({"zone": zone, "bus_v": round(bus_v, 2), "alert": "main_power_lost"})
        client.publish("solar-heat/{}/power_alert".format(zone), payload)
        client.disconnect()
        print("[PowerAlert] sent bus_v={}V".format(round(bus_v, 2)))
    except Exception as e:
        print("[PowerAlert] ERROR:", e)


# --- 起動 ---
wdt = machine.WDT(timeout=WDT_TIMEOUT)
wifi_off()

# SDマウント。失敗してもraiseしない（センサー測定とMQTT送信は続ける）
if mount_sd():
    print("[Boot] SD mounted OK")
else:
    print("[Boot] SD mount failed - continuing without SD logging")

# 初期LED状態を反映（起動時SD失敗時は即点滅）
bus_v_initial = read_bus_voltage()
set_led_state(
    power_alert=(bus_v_initial < POWER_THRESHOLD_V),
    sd_alert=(sd_status != "ok"),
)

# 初回のみNTP同期
wdt.feed()
if connect_wifi():
    sync_ntp()
    wifi_off()
wdt.feed()


# --- メインループ ---
while True:
    wdt.feed()
    wifi_off()
    ts    = jst_time()
    data  = read_sensors()
    wdt.feed()
    bus_v = read_bus_voltage()
    print(ts[:6], data, "bus={}V".format(round(bus_v, 2)))

    # SDヘルスチェック付き書き込み
    log_to_sd_with_recovery(ts, data)
    wdt.feed()

    # アラート状態を判定してLED反映
    power_alert = bus_v < POWER_THRESHOLD_V
    sd_alert    = sd_status not in ("ok", "ok_after_remount")
    set_led_state(power_alert, sd_alert)

    # WiFi ON → 送信 → WiFi OFF
    if connect_wifi():
        wdt.feed()
        ok_mqtt    = send_mqtt(ts, data)
        wdt.feed()
        ok_ambient = send_ambient(data)
        wdt.feed()
        send_status(ts, bus_v)
        if power_alert:
            print("[PowerAlert] bus={}V < {}V".format(round(bus_v, 2), POWER_THRESHOLD_V))
            send_power_alert(bus_v)
        wifi_off()
        if ok_mqtt or ok_ambient:
            blink_tx(2)
    else:
        print("WiFi unavailable - SD only")
        wifi_off()

    for _ in range(INTERVAL_SEC):
        wdt.feed()
        time.sleep(1)

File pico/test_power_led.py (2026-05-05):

"""電源監視 + 赤LED連動テスト（高速ループ）
SDやWiFiは使わず、ADCとLEDだけで動作確認。
"""
import machine
import time

POWER_THRESHOLD_V = 4.0

adc = machine.ADC(26)
led = machine.Pin(15, machine.Pin.OUT)

print("Power monitor test (Ctrl+C to stop)")
while True:
    bus_v = adc.read_u16() / 65535 * 3.3 * 2
    if bus_v < POWER_THRESHOLD_V:
        led.on()
        state = "ALERT"
    else:
        led.off()
        state = "OK"
    print("bus={:.2f}V  {}".format(bus_v, state))
    time.sleep(1)

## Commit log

2026-03-29 initial: solar heat soil temperature trial project
2026-03-29 docs: add sensor registry with Pico1 zone-a assignments
2026-03-29 refactor: change to single 1-Wire bus on GP28 for all sensors
    - main.py: PIN_BUS1/BUS2 → PIN_BUS(28), added ID_OUTDOOR to SENSOR_MAP
    - config_example.py: added ID_OUTDOOR, removed bus comments
    - pcb_spec.md: GP21/GP22 → GP28 single bus, 7 connectors, 1 pull-up
    - sensor_registry.md: all sensors reassigned to GP28
2026-03-29 feat: load sensor map from SD card (sensor_map.json)
    - main.py: zone and sensor ID mapping loaded from /sd/sensor_map.json
    - config_example.py: removed hardcoded sensor IDs (now in SD card)
    - sensor_map_pico1.json: zone-a sensor assignments for Pico1
    - sensor_map_template.json: template for Pico2/3
2026-03-29 fix: INTERVAL_SEC 30分に変更、デバッグprint追加、PCB仕様書更新
    - main.py: INTERVAL_SEC 600→1800秒（30分）
    - main.py: WiFi/SD/Ambient/MQTT の成功・失敗をシリアルに出力
    - pcb_spec.md: GPIO割り当てをGP2-5（実機確認済み）に修正
    - pcb_spec.md: 電源設計注意事項・サージ対策・外部LDO構成を追記
    - WiFiとSDが同じ3V3レールを共有→電圧降下問題の記録
    - SDモジュールVDD直近に100nFセラコン必須
    - TVSダイオード・100Ω直列抵抗によるサージ/静電気保護
    - AMS1117等による外部LDO分離構成を検討項目として記載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
    [main.py]
2026-03-29 feat: SDログをワイド形式（センサごとに列）に変更
    - log_to_sd: 縦持ち（1行1センサ）→ 横持ち（1行1タイムスタンプ）
    - 列順は sensor_map のラベルをソートして固定
    - センサが未検出の場合は空欄で記録
2026-03-29 chore: INTERVAL_SEC 30秒に変更（デバッグ継続用）
2026-03-29 feat: センサーCSVラベルをS1〜S7形式に変更、PCB電源設計注意事項に実測値追記
    - sensor_map: center_10cm等 → S1_center_10cm等（番号+意味の複合形式）
    - sensor_registry: CSVラベル列を追加
    - pcb_spec: 2026-03-29実機トラブル記録追記（端子台緩み・2.9V実測）
2026-04-01 fix: SD card detect pin GP20 → GP6（PCBレイアウト都合）
    [main.py]
2026-04-01 docs: SD 6ピン一列接続のPCB設計メモを追記（物理ピン4-9）
2026-04-01 docs: pcb_spec 大幅更新（統合基板・MCP1703・ダイオードOR・電源監視回路）
    - 基板をセンサー/SD統合1枚構成に変更
    - LDO: AMS1117-3.3 → MCP1703-3302（ドロップアウト250mV）
    - バックアップ電源: 単3×4本 + ダイオードOR回路追加
    - 主電源監視回路（分圧→GPIO）追加
    - 外部接続をフェルール端子（WAGO/Phoenix）に整理
2026-04-01 docs: pcb_spec を上流電源ボックス＋PicoBox分離構成に更新
    - 上流ボックス: 24V→5V DC-DC + 電池ボックス(単3×3本) + ダイオードOR回路
    - PicoBox: 5Vバス受け、バッテリー回路は上流に集約
    - 3台共通設計を明記
2026-04-01 feat: 1-Wire バスを GP28 → GP7 に変更（物理ピン4-10の7ピン連続集約）
    - main.py: PIN_BUS = 28 → 7
    - pcb_spec: 7ピン連続接続の設計メモ追記
    - sensor_registry: GPIOバス列を GP7 に更新
2026-04-01 docs: ブログ下書き追加（2026-04-01 ファームウェア完成・PCB設計思考メモ）
2026-04-01 docs: ブログ記事に電源設計セクションを追記（WiFi干渉・LDO選定・ダイオードOR・サージ対策）
2026-04-01 docs: ブログ下書き追加（試験計画・太陽熱養生の目的と試験区説明）
2026-04-02 docs: 試験計画ブログ記事を完成（動機・BLOF・試験区・スケジュール）
2026-04-02 docs: 試験計画に土壌診断を追加（養生前・直後・作付け前の3回）
2026-04-02 docs: 土壌診断を専門機関依頼に確定
2026-04-02 docs: 土壌診断の依頼先をジャパンバイオファームに確定
2026-04-02 feat: PicoBox KiCAD schematic complete + DS18B20 individual GPIO
    ## 設計変更
    - DS18B20を1-Wireバス（GP7）から個別GPIO方式（GP8-GP14）に変更
    - 1センサー1GPIO・sensor_map廃止・IDスキャン不要
    - 1本故障時の影響を他センサーに波及させない
    - TVS: P6KE6.8A（単方向）→ P6KE6.8CA（双方向）
    - SDモジュール: AE-MICRO-SD-DIP 10ピン対応
    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
    [picobox.kicad_pcb, picobox.kicad_sch]
2026-04-11 feat: PicoBox PCB完成・部品発注完了
    - PCBレイアウト・DRC完了（エラー0件）、JLCPCB発注済み（5枚 $4.64）
    - J9ピンアサイン修正（SD_CD=PIN10, GND=PIN9）
    - Gerberファイル追加（kicad/gerver.zip）
    - KiCAD PCBレイアウト・回路図最終版を反映
    - docs/pcb_spec.md: 全部品の購入先・品番確定、調達状況セクション追加
    - Mouser: MCP1703 / P6KE6.8CA-TB / SPTAF端子台 / Pico W / SD-15B-05
    - 秋月: 抵抗・コンデンサ・LED・スイッチ・ポリスイッチ 等
    [picobox.kicad_pcb, picobox.kicad_sch, picobox.step]
2026-04-20 docs: note記事1本目追加（太陽熱養生・動機記事）
2026-04-24 add blog article 2 draft and supporting figures
    - note_02: firmware and PCB design article draft (section 6 pending)
    - style_guide.md: writing style reference
    - gen_picobox_diagram.py: PicoBox block diagram (routing bugs fixed, rocker switch added)
    - gen_gantt.py / gen_zones.py / gen_depth.py: supporting figures
    - picobox_diagram.drawio: hand-drawn block diagram (final version for article)
    - fig_pcb_3d.png: KiCAD 3D render of PicoBox PCB
2026-05-03 feat: 電源監視（GP26 ADC）をファームウェアに追加
    - read_bus_voltage(): 10kΩ/10kΩ分圧からバス電圧を計算
    - send_power_alert(): 電源断時にMQTTアラート送信
    - メインループで毎回電圧計測・閾値（4.0V）以下でアラート
2026-05-05 feat: ラズパイサーバー構築（Mosquitto + Python MQTT logger + SQLite）
    - server/: MQTT購読 → SQLite保存スクリプト + systemdユニット
    - docs/server_design.md: サーバー全体設計
    - docs/sensor_registry.md: PCB実装後のセンサー対応表更新
    - pico/main.py: 電源アラート時の赤LED点灯追加
    - pico/test_*.py: 動作確認用スクリプト
    - docs/blog/: 部品表画像生成スクリプト追加
    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
2026-05-05 fix: systemdユーザーをpiからnonoに修正
2026-05-05 feat: Grafana SQLite データソース provisioning 追加
2026-05-05 docs: サーバー設計書を実装結果に合わせて更新
    - 構築結果（End-to-End動作確認済み）を追記
    - 実装上のハマりポイントを記録
    - アクセス情報・残作業をまとめ
2026-05-05 fix: WiFi接続を一度OFF→ONしてリトライ追加（最大2回試行）
    毎回WiFi OFF/ON するシーケンスで接続が不安定になりやすかった問題に対処。
    - 接続前に明示的に wlan.active(False) → 500ms 待機 → wlan.active(True)
    - 1回失敗時は同じシーケンスをもう1回試行
    - 最大合計約42秒で諦め、次の30分サイクルへ
    電力消費を抑えるためリトライは1回のみ。データバッファリングは未実装。
    [main.py]
2026-05-06 feat: SDヘルス監視・ステータス送信・LED状態機械を追加
    Pico:
    - SD失敗時の起動停止を廃止（ソフト失敗化）
    - log_to_sd_with_recovery: 書き込み失敗時に自動再マウント
    - sd_status / last_wifi_attempts / boot_time をグローバルで保持
    - send_status: solar-heat/{zone}/status トピックに送信
    - LED状態機械: 消灯/常時点灯(電源)/低速点滅(SD)/高速点滅(両方)
    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
2026-05-06 fix: Picoファーム本番化 - センサー状態追跡・uptime修正
    - センサー状態 dict (sensor_status) 追加。読取り毎にOK/NG更新
    - send_status() に ts引数・sensors_ok/sensors_ng を含める
    - boot_time を NTP同期後に記録（同期前 time.time() 使用による
    uptime誤計測の修正）
    - INTERVAL_SEC コメント整理
    [main.py]
2026-07-12 feat: GCE MQTTブローカー対応 — MQTT認証追加・接続先変更
    - pico/main.py: MQTTClient に user/password パラメータ追加（3箇所）
    - server/mqtt_logger.py: MQTT_USER/MQTT_PASS 環境変数対応
    - server/mqtt_logger.service: 接続先を GCE (34.58.138.105) に変更
    - docs/server_design.md: ラズパイ構成ドキュメント全面更新
2026-07-12 docs: README.md 全面改訂 — システム概要図・セットアップ手順・運用コマンド集
    - システム概要図（system_overview.png）とPicoBox回路図を追加
    - データの流れ、ブラウザからの確認方法、全コンポーネント一覧を網羅
    - GCE MQTT中継サーバーの情報を追加
    - セットアップ手順・運用コマンド集を整備
2026-07-19 feat: GCEサーバー一元化 — セットアップスクリプト・WebSocket・認証追加
2026-07-19 feat: PicoBox A↔C入替対応 — ZONE_REMAP・DB修正・ダッシュボード・ドキュメント
    - mqtt_logger.py に ZONE_REMAP 追加（zone-a↔zone-c 受信時変換）
    - Grafana ダッシュボード新規追加（ワイドフォーマットSQL、全6パネル）
    - sensor_registry.md に圃場配置変更・プローブ交換を記録
    - server_design.md を現行アーキテクチャ（GCE+Pi二重化）に全面改訂
2026-07-19 fix: LABEL_REMAP追加 — プローブ物理位置とファームラベルのずれを受信時に変換
    コネクタ変更なしでプローブを土中移動したため、GPIOベースの
    ファームラベルと実際の計測位置が不一致だった。
    mqtt_logger.py で受信時にラベルを物理位置に変換して解決。
2026-07-20 feat: REMAP廃止・ウォッチドッグ追加・ドキュメント更新
    - mqtt_logger.py: ZONE_REMAP/LABEL_REMAP削除、CallbackAPIVersion削除(paho 1.x互換)
    - main.py: ウォッチドッグタイマー(8秒)追加、config.SENSOR_PINS上書き対応
    - config_pico1/2/3.py: 各ユニットの正しいZONE・SENSOR_PINS設定
    - docs: ゾーン名修正、REMAP廃止の経緯、API情報追加
    [main.py]
2026-07-28 feat: センサーラベル修正 — 10cm→15cm、区A/BのS7を土壌5cmに変更
    実際の埋設深さは15cmだったため S1/S4 のラベルを修正（過去データも同深さ）。
    区A・区Bの GP14 は外気温から土壌5cm（BLOF公式の基準深さ）に差し替え。
    途中からの計測のため参考値扱いとし、積算温度の計算には含めない。
    区C は外気温のまま。
    [main.py]
2026-07-28 Revert "feat: センサーラベル修正 — 10cm→15cm、区A/BのS7を土壌5cmに変更"
    This reverts commit 76d94f094b5fe2e4a9e475dc4f76b074e786d5e8.
    [main.py]
2026-07-28 docs: ラベルと実深さのずれを台帳に明記
    ラベル改名は見送り（ファーム書き換えが農場限定のため）。
    実態とのずれはHP表示側で補正している旨を記載。
2026-07-30 sec: クレデンシャルをgit管理から除去し.env方式に移行
    WiFi/MQTT/Ambientのパスワード・APIキーがREADME・config・serviceファイルに
    べた書きされていたため、.envファイルに分離しgitignore対象に変更。
